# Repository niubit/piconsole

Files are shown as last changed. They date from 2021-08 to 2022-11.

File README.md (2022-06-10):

# PiConsole - Raspberry Pi Pico Retro Console

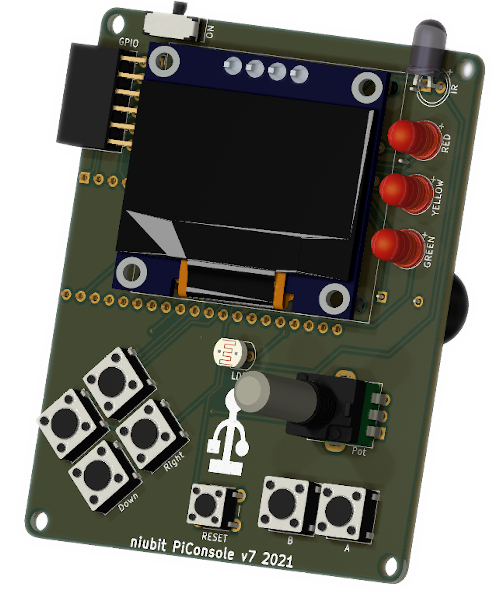
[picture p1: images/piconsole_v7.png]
PiConsole render


This repository has submodules. To clone add the `--recursive` option to the git clone command:

```
git clone --recursive https://github.com/niubit/piconsole.git
```

You can see a brief description (in spanish) in [this site](https://niubitbox.niubit.es/docs/niubitbox005/). A full description in english is available in [Instructables](https://www.instructables.com/PiConsole-Raspberry-Pi-Pico-Retro-Console/).

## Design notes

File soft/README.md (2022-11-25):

# PiConsole Software

Firmware collection for PiConsole.

## Firmware list

### CoderDojo Twin Cities

* Description: Code from the examples that appear on the [MicroPython for Kids](https://www.coderdojotc.org/micropython/) website, a great site that is highly recommended if you want to advance in learning the Python language.
* Folder: [CoderDojo_Twin_Cities](https://github.com/niubit/piconsole_soft/tree/master/CoderDojo_Twin_Cities)
* Environment: MicroPython
    * [oled_displays_pot.py](https://github.com/niubit/piconsole_soft/raw/master/CoderDojo_Twin_Cities/oled_displays_pot.py) + [ssd1306.py](https://github.com/niubit/piconsole_soft/raw/master/CoderDojo_Twin_Cities/ssd1306.py): [OLED Displays > OLED Pot](https://www.coderdojotc.org/micropython/oled/12-oled-pot/)

### MegaGamesCompilationPicoAdafruit

* Description: Collection of 16 games written in C adapted for Raspberry Pi Pico from [this version](https://www.tinyjoypad.com/esp8285) for ESP8266.
* Folder: [MegaGamesCompilationPicoAdafruit](https://github.com/niubit/piconsole_soft/tree/master/MegaGamesCompilationPicoAdafruit)
* Environment: Arduino IDE
* Code: https://github.com/tscha70/MegaGamesCompilationPicoAdafruit
* Installation: [MegaGamesCompilationPicoAdafruit.uf2](https://github.com/niubit/piconsole_soft/raw/master/MegaGamesCompilationPicoAdafruit/MegaGamesCompilationPicoAdafruit.uf2)
* Controls:
    * D-pad: Directions
    * A: Fire

### MorseCodeCreator

* Description: Morse code translator.
* Folder: [MorseCodeCreator](https://github.com/niubit/piconsole_soft/tree/master/MorseCodeCreator)
* Environment: MicroPython
* Original code: https://github.com/printnplay/Pico-MicroPython/blob/main/MorseCodeCreator.py
* Installation: Install [firmware MicroPython](https://micropython.org/download/rp2-pico/) and load the file [MorseCodeCreator.py](https://github.com/niubit/piconsole_soft/raw/master/MorseCodeCreator/MorseCodeCreator.py) (rename as `main.py` for autorun). The output of the program is produced by the USB port, not by the screen. A serial port client must be connected to that port set to 115200 baud.
* Controls:
    * A: Pulse (long or short depending on the time; the red LED lights up when the pulse is short or the green LED lights up when the pulse is long.)

### Phantom Slayer

* Description: Classic game version of Tandy Color Computer Phantom Slayer.
* Folder: [Phantoms](https://github.com/niubit/piconsole_soft/tree/master/Phantoms)
* Environment: [VS Code](https://code.visualstudio.com/)
* Original code: [Site](https://smittytone.net/pico-phantoms/), [Repo](https://github.com/smittytone/pi-pico)
* Installation: [phantoms.uf2](https://github.com/niubit/piconsole_soft/raw/master/Phantoms/phantoms.uf2)
* Controls:
    * Up: Forward
    * Down: Backward
    * Right: Turn right
    * Left: Turn left
    * A: Fire
    * B: Teleport

### PiConsole games

* Description: Simple MicroPython games adapted to the PiConsole hardware.
* Folder: [PiConsole_games](https://github.com/niubit/piconsole_soft/tree/master/PiConsole_games)
* Environment: MicroPython with [web IDE adapted to PiConsole](https://piconsole.niubit.net/).
* Installation: Install [firmware MicroPython](https://micropython.org/download/rp2-pico/) and [lib](https://github.com/niubit/piconsole_soft/tree/master/thumby_mod/lib) directory from `thumby_mod` (this is automatically achieved by using the `FORMAT` button in the [Thumby IDE adapted to PiConsole](https://piconsole.niubit.net/)). Then load the games separately (rename as `main.py` for autorun).

### Tamaguino

* Description: Virtual pet inspired by Tamagotchi.
* Folder: [Tamaguino](https://github.com/niubit/piconsole_soft/tree/master/Tamaguino)
* Environment: Arduino IDE
* Original code: [Site](https://alojzjakob.github.io/Tamaguino/), [Repo](https://github.com/alojzjakob/Tamaguino)
* Installation: [Tamaguino.ino.uf2](https://github.com/niubit/piconsole_soft/raw/master/Tamaguino/Tamaguino.ino.uf2)
* Controls:
    * Up: Menu
    * Down: Status or Accept
    * Right: Back

### Picotamachibi

* Description: Virtual pet inspired by Tamagotchi.
* Folder: [picotamachibi](https://github.com/niubit/piconsole_soft/tree/master/picotamachibi)
* Environment: MicroPython with [web IDE adapted to PiConsole](https://piconsole.niubit.net/).
* Original code: https://github.com/kevinmcaleer/picotamachibi
* Installation: Install [firmware MicroPython](https://micropython.org/download/rp2-pico/). Then load all the files from folder (rename `picotamachibi.py` as `main.py` for autorun).
* Controls:
    * Right: Select
    * A: Accept
    * B: Back

### Colección Cheungbx

* Description: Collection of Python mini-games.
* Folder: [coleccion_cheungbx](https://github.com/niubit/piconsole_soft/tree/master/coleccion_cheungbx)
* Environment: MicroPython
* Original code: https://github.com/niubit/gameESP-micropython/
* Installation: Install [firmware MicroPython](https://micropython.org/download/rp2-pico/) and load the [gameESP.py](https://github.com/niubit/piconsole_soft/raw/master/coleccion_cheungbx/gameESP.py) library. Then the games themselves (rename as `main.py` for autorun).
* Controls:
    * You can toggle between analogue and digital control by pressing Up in the options menu of each game.

### Demo Adafruit para SSD1306 SPI

* Description: Demo of the capabilities of the Adafruit SSD1306 library.
* Folder: [oled_demo](https://github.com/niubit/piconsole_soft/tree/master/oled_demo)
* Environment: Arduino IDE
* Original code: https://github.com/adafruit/Adafruit_SSD1306/blob/master/examples/ssd1306_128x64_spi/ssd1306_128x64_spi.ino
* Installation: Required `Adafruit SSD1306` library. [oled_demo.ino.uf2](https://github.com/niubit/piconsole_soft/raw/master/oled_demo/oled_demo.uf2)

### Pico Invaders

* Description: Vertical screen Space Invaders with analogue control.
* Folder: [picoinvaders](https://github.com/niubit/piconsole_soft/tree/master/picoinvaders)
* Environment: MicroPython
* Original code: https://github.com/printnplay/Pico-MicroPython/blob/main/picoinvaders.py
* Installation: Install [firmware MicroPython](https://micropython.org/download/rp2-pico/) and load the files [picoinvaders.py](https://github.com/niubit/piconsole_soft/raw/master/picoinvaders/picoinvaders.py) (rename as `main.py` for autorun) and [ssd1306.py](https://github.com/niubit/piconsole_soft/raw/master/picoinvaders/ssd1306.py).
* Controls:
    * Potentiometer: Movement
    * Auto fire

### Pico Invaders with buttons

* Description: Vertical screen Space Invaders with digital control.
* Folder: [picoinvaders_with_buttons](https://github.com/niubit/piconsole_soft/tree/master/picoinvaders_with_buttons)
* Environment: MicroPython
* Original code: https://github.com/printnplay/Pico-MicroPython/blob/main/PicoInvadersWithButtons.py
* Installation: Install [firmware MicroPython](https://micropython.org/download/rp2-pico/) and load the files [PicoInvadersWithButtons.py](https://github.com/niubit/piconsole_soft/raw/master/picoinvaders_with_buttons/PicoInvadersWithButtons.py) (rename as `main.py` for autorun) and [ssd1306.py](https://github.com/niubit/piconsole_soft/raw/master/picoinvaders_with_buttons/ssd1306.py).
* Controls:
    * Up/Down: Movement (left/right)
    * A: Fire

### Reflejos2

* Description: A reaction game for two players. The code is only 32 lines long so it is easy to follow and is an example of how much can be done with few lines of code. On start-up, the red LED lights up for 5 to 10 seconds. Players must press their button as soon as they see the light go out. When they do so, the screen shows which of the two players was the fastest.
* Folder: [reflejos2](https://github.com/niubit/piconsole_soft/tree/master/reflejos2)
* Environment: MicroPython
* Installation: Install [firmware MicroPython](https://micropython.org/download/rp2-pico/) and load the files [reflejos2.py](https://github.com/niubit/piconsole_soft/raw/master/reflejos2/reflejos2.py) (rename as `main.py` for autorun) and [ssd1306.py](https://github.com/niubit/piconsole_soft/raw/master/reflejos2/ssd1306.py).
* Controls:
    * A: Player 1
    * B: Player 2

### Test PiConsole

* Description: PiConsole I/O test program.
* Folder: [test_piconsole](https://github.com/niubit/piconsole_soft/tree/master/test_piconsole)
* Environment: Arduino IDE
* Installation: Librería `Adafruit SSD1306` needed. [test_piconsole.uf2](https://github.com/niubit/piconsole_soft/raw/master/test_piconsole/test_piconsole.uf2)
* Controls:
    * Up: Lights up IR LED (view it through a mobile phone camera)
    * Left: Lights up red LED
    * Right: Lights up yellow LED
    * Down: Lights up green LED
    * A y B: Beeps
    * Potentiometer: Controls top bar on screen
    * Photoresistor LDR: Controls bottom bar on screen

### Games Thumby

* Description: Games made for Thumby by the community, compatible with PiConsole.
* Folder: [thumby_games](https://github.com/niubit/piconsole_soft/tree/master/thumby_games)
* Environment: MicroPython with [web IDE adapted to PiConsole](https://piconsole.niubit.net/).
* Installation: Install [firmware MicroPython](https://micropython.org/download/rp2-pico/) and [lib](https://github.com/niubit/piconsole_soft/tree/master/thumby_mod/lib) directory from `thumby_mod` (this is automatically achieved by using the `FORMAT` button in the [Thumby IDE adapted to PiConsole](https://piconsole.niubit.net/)). Then load the games separately (rename to `main.py` to make it run automatically).

### Adaptation of the Thumby platform

* Description: [Thumby](https://www.indiegogo.com/projects/thumby-the-tiny-playable-keychain#/) default games. These are the same games that are installed by using the `FORMAT` button in the [Thumby IDE adapted to PiConsole](https://piconsole.niubit.net/).
* Folder: [thumby_mod](https://github.com/niubit/piconsole_soft/tree/master/thumby_mod)
* Environment: MicroPython with [web IDE adapted to PiConsole](https://piconsole.niubit.net/).
* Original code: https://github.com/TinyCircuits/tinycircuits.github.io/tree/master/ThumbyGames
* Installation: Install [firmware MicroPython](https://micropython.org/download/rp2-pico/) and upload all the files following the directory structure.
* Controls: D-pad + A + B

### CHIP-8 emulator

* Description: [CHIP-8](https://es.wikipedia.org/wiki/CHIP-8) virtual system emulator.
* Folder: [chip-8_emulator](https://github.com/niubit/piconsole_soft/tree/master/chip-8_emulator)
* Environment: MicroPython with [web IDE adapted to PiConsole](https://piconsole.niubit.net/).
* Original code: https://github.com/Wireframe-Magazine/Wireframe-54/tree/main/emulator-guide/pychip8
* Installation: Install [firmware MicroPython](https://micropython.org/download/rp2-pico/) and upload all the files following the directory structure.
* Controls: D-pad + A + B mapped in file `cpu.py`

## Pins - Components

* Pot
    * ADC1
* LDR
    * ADC2
* LED
    * GP8 -> Yellow
    * GP9 -> Red
    * GP21 -> Green
    * GP22 -> IR
* Buzzer
    * GP10
* Controls
    * GP11 -> Fire A
    * GP7  -> Fire B
    * GP12 -> Right
    * GP13 -> Left
    * GP14 -> Down
    * GP15 -> Up
* OLED
    * GP16 -> DC
    * GP17 -> CS
    * GP18 -> SCL  //SCK
    * GP19 -> SDA  //MOSI
    * GP20 -> RES

## Arduino IDE environment

Follow [this instructions](https://arduino-pico.readthedocs.io/en/latest/install.html#installing-via-arduino-boards-manager) to add the Pico as a supported board in Arduino IDE.

## Libraries

* MicroPython
    * https://github.com/adafruit/micropython-adafruit-ssd1306
    * https://github.com/adafruit/micropython-adafruit-gfx
* CircuitPython
    * https://github.com/adafruit/Adafruit_CircuitPython_SSD1306
    * https://github.com/adafruit/Adafruit_CircuitPython_GFX

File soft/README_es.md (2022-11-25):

# PiConsole Software

Colección de firmware para PiConsole.

## Lista de firmware

### CoderDojo Twin Cities

* Descripción: Código de los ejemplos que aparecen en la web [MicroPython for Kids](https://www.coderdojotc.org/micropython/), un gran sitio muy recomendable si se quiere avanzar en el aprendizaje del lenguaje Python.
* Directorio: [CoderDojo_Twin_Cities](https://github.com/niubit/piconsole_soft/tree/master/CoderDojo_Twin_Cities)
* Entorno: MicroPython
    * [oled_displays_pot.py](https://github.com/niubit/piconsole_soft/raw/master/CoderDojo_Twin_Cities/oled_displays_pot.py) + [ssd1306.py](https://github.com/niubit/piconsole_soft/raw/master/CoderDojo_Twin_Cities/ssd1306.py): [OLED Displays > OLED Pot](https://www.coderdojotc.org/micropython/oled/12-oled-pot/)

### MegaGamesCompilationPicoAdafruit

* Descripción: Colección de 16 juegos escritos en C adaptados para Raspberry Pi Pico de [esta versión](https://www.tinyjoypad.com/esp8285) para ESP8266.
* Directorio: [MegaGamesCompilationPicoAdafruit](https://github.com/niubit/piconsole_soft/tree/master/MegaGamesCompilationPicoAdafruit)
* Entorno: Arduino IDE
* Código: https://github.com/tscha70/MegaGamesCompilationPicoAdafruit
* Instalación: [MegaGamesCompilationPicoAdafruit.uf2](https://github.com/niubit/piconsole_soft/raw/master/MegaGamesCompilationPicoAdafruit/MegaGamesCompilationPicoAdafruit.uf2)
* Controles:
    * Cruceta: Direcciones
    * A: Disparo

### MorseCodeCreator

* Descripción: Traductor de código Morse.
* Directorio: [MorseCodeCreator](https://github.com/niubit/piconsole_soft/tree/master/MorseCodeCreator)
* Entorno: MicroPython
* Código original: https://github.com/printnplay/Pico-MicroPython/blob/main/MorseCodeCreator.py
* Instalación: Instalar [firmware MicroPython](https://micropython.org/download/rp2-pico/) y cargar el archivo [MorseCodeCreator.py](https://github.com/niubit/piconsole_soft/raw/master/MorseCodeCreator/MorseCodeCreator.py) (renombrar a `main.py` para que se ejecute automáticamente). La salida del programa se produce por el puerto USB, no por pantalla. Hay que conectar un cliente de puerto serie a ese puerto configurado a 115200 baudios.
* Controles:
    * A: Pulso (largo o corto según el tiempo; se enciende el LED rojo en pulso corto o el verde al hacerse largo)

### Phantom Slayer

* Descripción: Versión de juego clásico de Tandy Color Computer Phantom Slayer.
* Directorio: [Phantoms](https://github.com/niubit/piconsole_soft/tree/master/Phantoms)
* Entorno: [VS Code](https://code.visualstudio.com/)
* Código original: [Sitio](https://smittytone.net/pico-phantoms/), [Repo](https://github.com/smittytone/pi-pico)
* Instalación: [phantoms.uf2](https://github.com/niubit/piconsole_soft/raw/master/Phantoms/phantoms.uf2)
* Controles:
    * Arriba: Adelante
    * Abajo: Atrás
    * Derecha: Girar derecha
    * Izquierda: Girar izquierda
    * A: Disparo
    * B: Teletransporte

### Juegos PiConsole

* Descripción: Juegos sencillos MicroPython adaptados al hardware de PiConsole.
* Directorio: [PiConsole_games](https://github.com/niubit/piconsole_soft/tree/master/PiConsole_games)
* Entorno: MicroPython con [IDE web adaptado a PiConsole](https://piconsole.niubit.net/).
* Instalación: Instalar [firmware MicroPython](https://micropython.org/download/rp2-pico/) y directorio [lib](https://github.com/niubit/piconsole_soft/tree/master/thumby_mod/lib) de `thumby_mod` (esto mismo se logra automáticamente usando el botón `FORMAT` en el [IDE de Thumby adaptado a PiConsole](https://piconsole.niubit.net/)). Luego cargar los juegos por separado (renombrar a `main.py` para que se ejecute automáticamente).

### Tamaguino

* Descripción: Mascota virtual inspirada en Tamagotchi.
* Directorio: [Tamaguino](https://github.com/niubit/piconsole_soft/tree/master/Tamaguino)
* Entorno: Arduino IDE
* Código original: [Sitio](https://alojzjakob.github.io/Tamaguino/), [Repo](https://github.com/alojzjakob/Tamaguino)
* Instalación: [Tamaguino.ino.uf2](https://github.com/niubit/piconsole_soft/raw/master/Tamaguino/Tamaguino.ino.uf2)
* Controles:
    * Arriba: Menú
    * Abajo: Estado o Aceptar
    * Derecha: Salir

### Picotamachibi

* Descripción: Mascota virtual inspirada en Tamagotchi.
* Directorio: [picotamachibi](https://github.com/niubit/piconsole_soft/tree/master/picotamachibi)
* Entorno: MicroPython con [IDE web adaptado a PiConsole](https://piconsole.niubit.net/).
* Código original: https://github.com/kevinmcaleer/picotamachibi
* Instalación: Instalar [firmware MicroPython](https://micropython.org/download/rp2-pico/). Luego todos los ficheros del directorio (renombrando `picotamachibi.py` a `main.py` para que se ejecute automáticamente).
* Controles:
    * Derecha: Seleccionar
    * A: Aceptar
    * B: Cancelar

### Colección Cheungbx

* Descripción: Colección de minijuegos Python.
* Directorio: [coleccion_cheungbx](https://github.com/niubit/piconsole_soft/tree/master/coleccion_cheungbx)
* Entorno: MicroPython
* Código original: https://github.com/niubit/gameESP-micropython/
* Instalación: Instalar [firmware MicroPython](https://micropython.org/download/rp2-pico/) y cargar la librería [gameESP.py](https://github.com/niubit/piconsole_soft/raw/master/coleccion_cheungbx/gameESP.py). Luego los juegos propiamente dichos (renombrando a `main.py` para que se ejecuten automáticamente).
* Controles:
    * Se puede alternar entre control analógico o digital al pulsar Arriba en el menú de opciones de cada juego.

### Demo Adafruit para SSD1306 SPI

* Descripción: Demo de las capacidades de la librería SSD1306 de Adafruit.
* Directorio: [oled_demo](https://github.com/niubit/piconsole_soft/tree/master/oled_demo)
* Entorno: Arduino IDE
* Código original: https://github.com/adafruit/Adafruit_SSD1306/blob/master/examples/ssd1306_128x64_spi/ssd1306_128x64_spi.ino
* Instalación: Necesaria librería `Adafruit SSD1306`. [oled_demo.ino.uf2](https://github.com/niubit/piconsole_soft/raw/master/oled_demo/oled_demo.uf2)

### Pico Invaders

* Descripción: Space Invaders de pantalla vertical con control analógico.
* Directorio: [picoinvaders](https://github.com/niubit/piconsole_soft/tree/master/picoinvaders)
* Entorno: MicroPython
* Código original: https://github.com/printnplay/Pico-MicroPython/blob/main/picoinvaders.py
* Instalación: Instalar [firmware MicroPython](https://micropython.org/download/rp2-pico/) y cargar los archivos [picoinvaders.py](https://github.com/niubit/piconsole_soft/raw/master/picoinvaders/picoinvaders.py) (renombrar a `main.py` para que se ejecute automáticamente) y [ssd1306.py](https://github.com/niubit/piconsole_soft/raw/master/picoinvaders/ssd1306.py).
* Controles:
    * Potenciómetro: Movimiento
    * Disparo automático

### Pico Invaders con botones

* Descripción: Space Invaders de pantalla vertical con control digital.
* Directorio: [picoinvaders_with_buttons](https://github.com/niubit/piconsole_soft/tree/master/picoinvaders_with_buttons)
* Entorno: MicroPython
* Código original: https://github.com/printnplay/Pico-MicroPython/blob/main/PicoInvadersWithButtons.py
* Instalación: Instalar [firmware MicroPython](https://micropython.org/download/rp2-pico/) y cargar los archivos [PicoInvadersWithButtons.py](https://github.com/niubit/piconsole_soft/raw/master/picoinvaders_with_buttons/PicoInvadersWithButtons.py) (renombrar a `main.py` para que se ejecute automáticamente) y [ssd1306.py](https://github.com/niubit/piconsole_soft/raw/master/picoinvaders_with_buttons/ssd1306.py).
* Controles:
    * Arriba/Abajo: Movimiento (izquierda/derecha)
    * A: Disparo

### Reflejos2

* Descripción: Juego de reflejos para dos jugadores. El código sólo tiene 32 líneas por lo que resulta fácil de seguir y es un ejemplo de lo mucho que se puede hacer con poco código. Al arrancar, se enciende el LED rojo entre 5 y 10 segundos. Los jugadores deben pulsar su botón nada más ver apagarse la luz. Al hacerlo se muestra en pantalla cual de los dos ha sido el más rápido.
* Directorio: [reflejos2](https://github.com/niubit/piconsole_soft/tree/master/reflejos2)
* Entorno: MicroPython
* Instalación: Instalar [firmware MicroPython](https://micropython.org/download/rp2-pico/) y cargar el archivo [reflejos2.py](https://github.com/niubit/piconsole_soft/raw/master/reflejos2/reflejos2.py) (renombrar a `main.py` para que se ejecute automáticamente) y [ssd1306.py](https://github.com/niubit/piconsole_soft/raw/master/reflejos2/ssd1306.py).
* Controles:
    * A: Jugador 1
    * B: Jugador 2

### Test PiConsole

* Descripción: Programa de test de entradas y salidas de PiConsole.
* Directorio: [test_piconsole](https://github.com/niubit/piconsole_soft/tree/master/test_piconsole)
* Entorno: Arduino IDE
* Instalación: Necesaria librería `Adafruit SSD1306`. [test_piconsole.uf2](https://github.com/niubit/piconsole_soft/raw/master/test_piconsole/test_piconsole.uf2)
* Controles:
    * Arriba => Enciende LED IR (visualizarlo a través de la cámara de un teléfono móvil)
    * Izquierda => Enciende LED rojo
    * Derecha => Enciende LED amarillo
    * Abajo => Enciende LED verde
    * Controles A y B => Hace sonar el zumbador
    * Potenciómetro => Controla barra superior en pantalla
    * Fotorresistencia LDR => Controla barra inferior en pantalla

### Juegos Thumby

* Descripción: Juegos hechos para Thumby por la comunidad, compatibles con PiConsole.
* Directorio: [thumby_games](https://github.com/niubit/piconsole_soft/tree/master/thumby_games)
* Entorno: MicroPython con [IDE web adaptado a PiConsole](https://piconsole.niubit.net/).
* Instalación: Instalar [firmware MicroPython](https://micropython.org/download/rp2-pico/) y directorio [lib](https://github.com/niubit/piconsole_soft/tree/master/thumby_mod/lib) de `thumby_mod` (esto mismo se logra automáticamente usando el botón `FORMAT` en el [IDE de Thumby adaptado a PiConsole](https://piconsole.niubit.net/)). Luego cargar los juegos por separado (renombrar a `main.py` para que se ejecute automáticamente).

### Adaptación plataforma Thumby

* Descripción: Juegos predeterminados de [Thumby](https://www.indiegogo.com/projects/thumby-the-tiny-playable-keychain#/). Son los mismos juegos que se instalan al usar el botón `FORMAT` en el [IDE de Thumby adaptado a PiConsole](https://piconsole.niubit.net/).
* Directorio: [thumby_mod](https://github.com/niubit/piconsole_soft/tree/master/thumby_mod)
* Entorno: MicroPython con [IDE web adaptado a PiConsole](https://piconsole.niubit.net/).
* Código original: https://github.com/TinyCircuits/tinycircuits.github.io/tree/master/ThumbyGames
* Instalación: Instalar [firmware MicroPython](https://micropython.org/download/rp2-pico/) y cargar todos los archivos siguiendo la estructura de directorios.
* Controles: Cruceta + A + B

### Emulador CHIP-8

* Descripción: Emulador del sistema virtual [CHIP-8](https://es.wikipedia.org/wiki/CHIP-8).
* Directorio: [chip-8_emulator](https://github.com/niubit/piconsole_soft/tree/master/chip-8_emulator)
* Entorno: MicroPython con [IDE web adaptado a PiConsole](https://piconsole.niubit.net/).
* Código original: https://github.com/Wireframe-Magazine/Wireframe-54/tree/main/emulator-guide/pychip8
* Instalación: Instalar [firmware MicroPython](https://micropython.org/download/rp2-pico/) y cargar todos los archivos siguiendo la estructura de directorios.
* Controles: Cruceta + A + B mapeables en fichero `cpu.py`

## Pines - Componentes

* Pot
    * ADC1
* LDR
    * ADC2
* LED
    * GP8 -> Amarillo
    * GP9 -> Rojo
    * GP21 -> Verde
    * GP22 -> IR
* Buzzer
    * GP10
* Controles
    * GP11 -> Disparo A
    * GP7  -> Disparo B
    * GP12 -> Derecha
    * GP13 -> Izquierda
    * GP14 -> Abajo
    * GP15 -> Arriba
* OLED
    * GP16 -> DC
    * GP17 -> CS
    * GP18 -> SCL  //SCK
    * GP19 -> SDA  //MOSI
    * GP20 -> RES

## Entorno Arduino IDE

Seguir [estas instrucciones](https://arduino-pico.readthedocs.io/en/latest/install.html#installing-via-arduino-boards-manager) para añadir la Pico como placa soportada en Arduino IDE.

## Librerías

* MicroPython
    * https://github.com/adafruit/micropython-adafruit-ssd1306
    * https://github.com/adafruit/micropython-adafruit-gfx
* CircuitPython
    * https://github.com/adafruit/Adafruit_CircuitPython_SSD1306
    * https://github.com/adafruit/Adafruit_CircuitPython_GFX

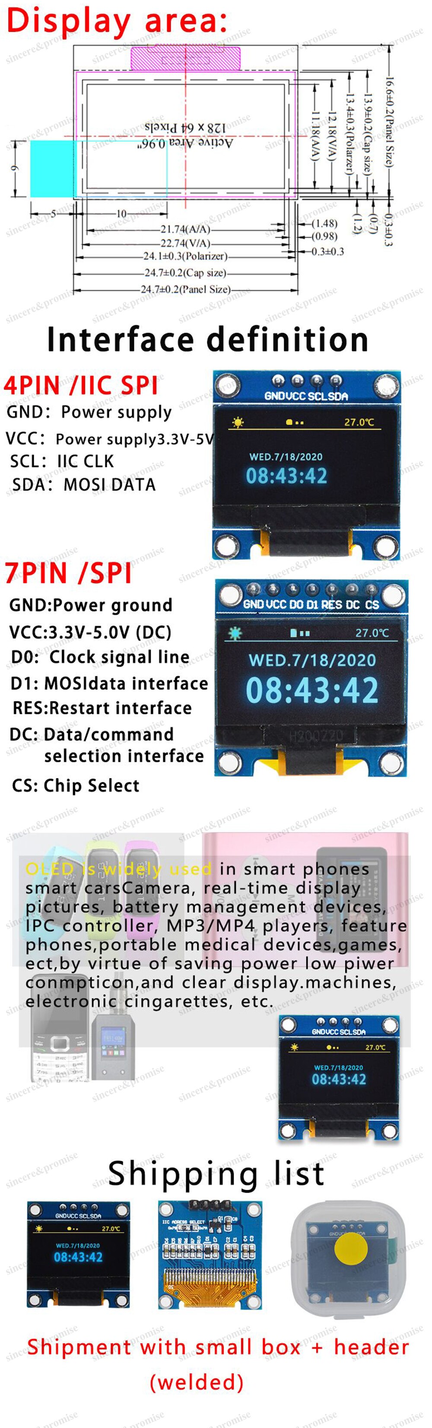
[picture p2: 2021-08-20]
pcb/images/oled2.jpg

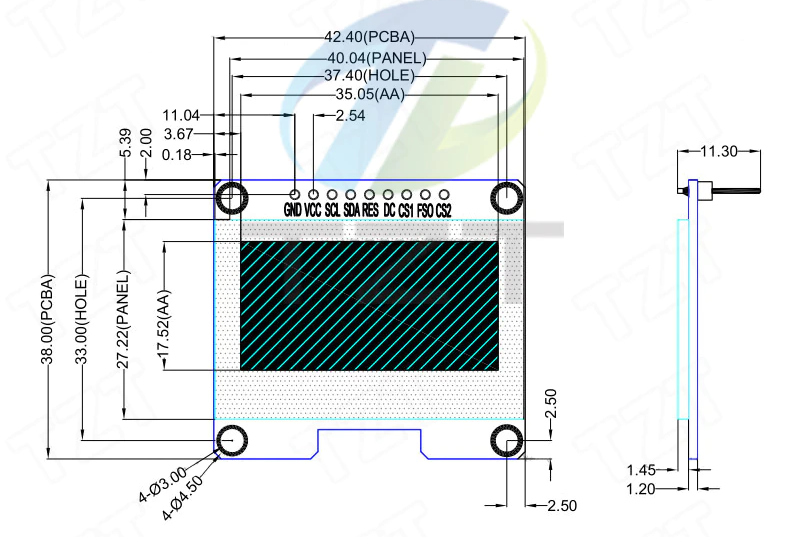
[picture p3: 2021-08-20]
pcb/images/ssd1309_dim.png

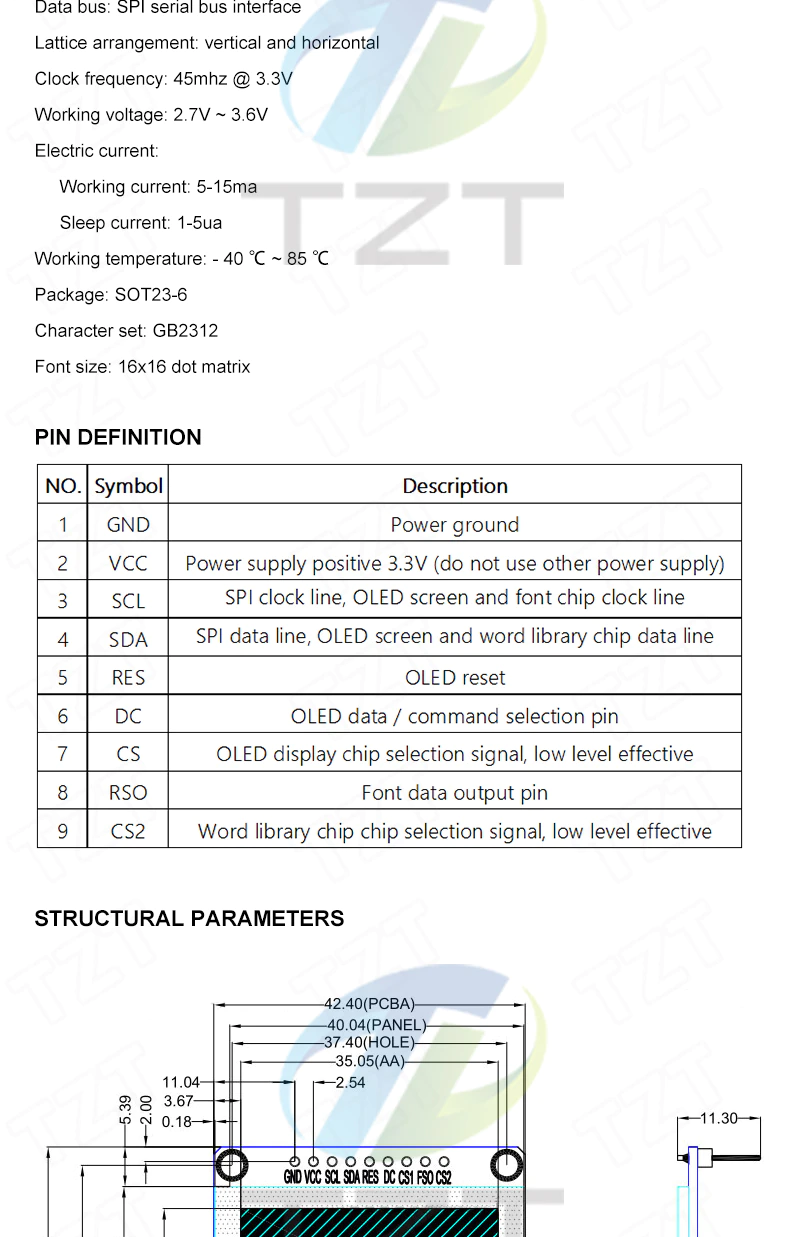
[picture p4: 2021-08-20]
pcb/images/ssd1309_1.png

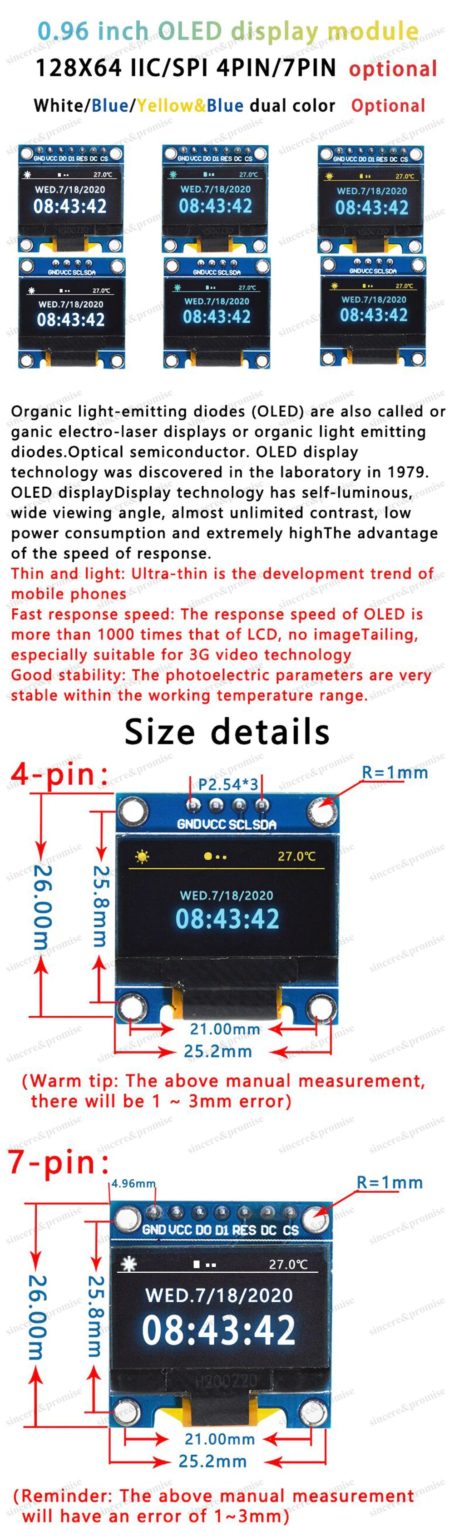
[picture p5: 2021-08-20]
pcb/images/oled1.jpg

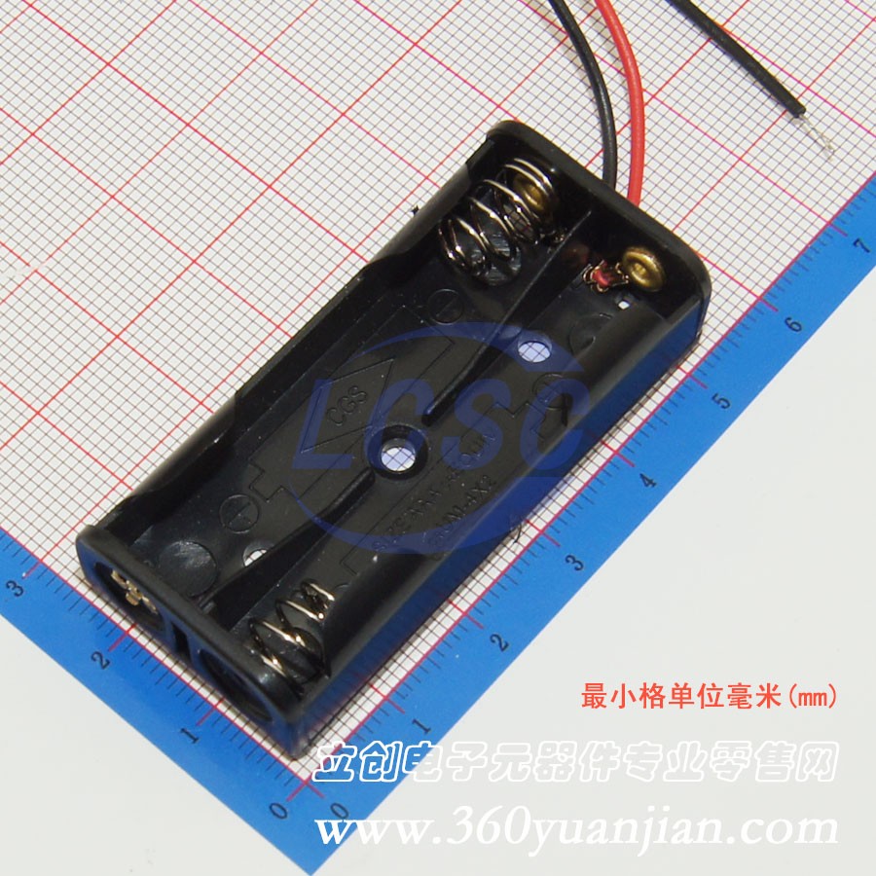
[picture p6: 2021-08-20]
pcb/images/battery_holder.jpg

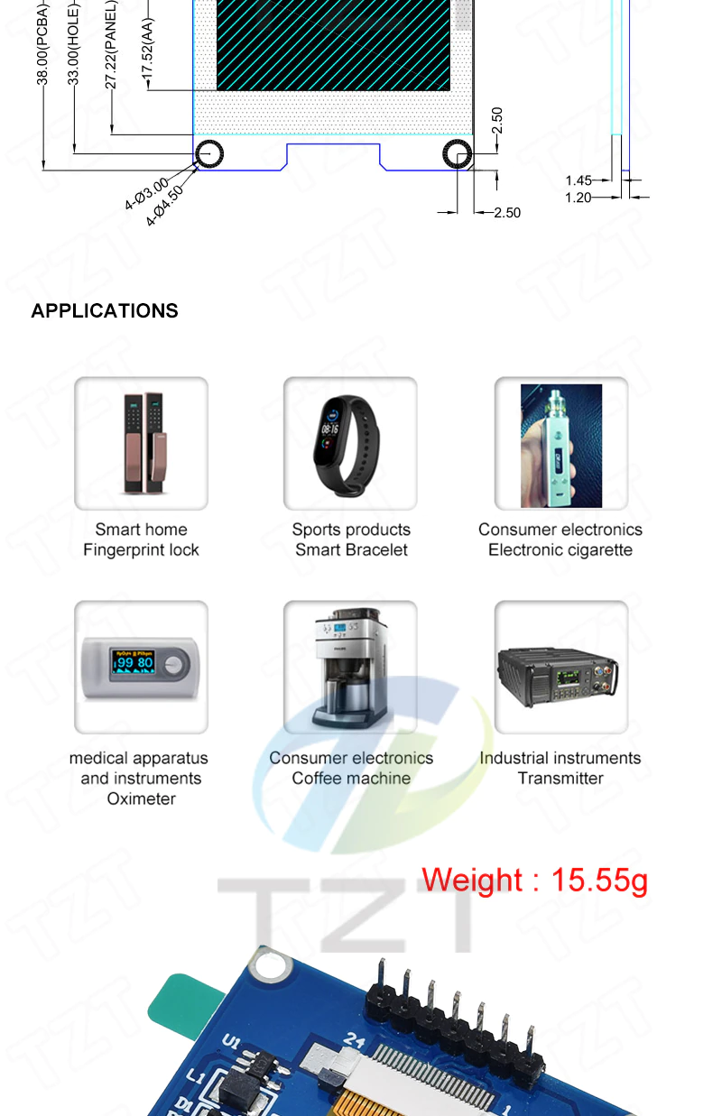
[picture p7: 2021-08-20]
pcb/images/ssd1309_2.png

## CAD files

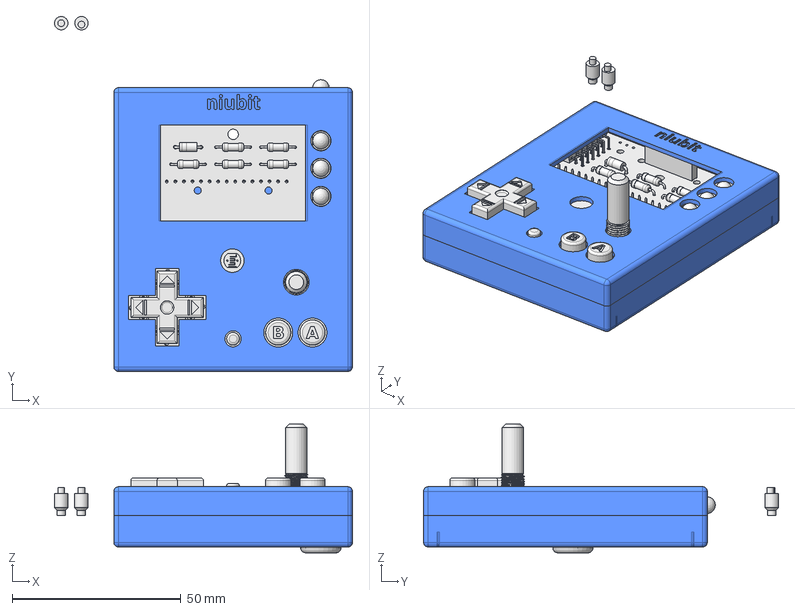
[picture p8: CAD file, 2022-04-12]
case/case.FCStd
88.4 x 105.3 x 38.2 mm
spacer_desviado
spacer_recto
pcb
cruceta
tecla_b001
tecla_a001
tecla_reset
inferior001
superior009

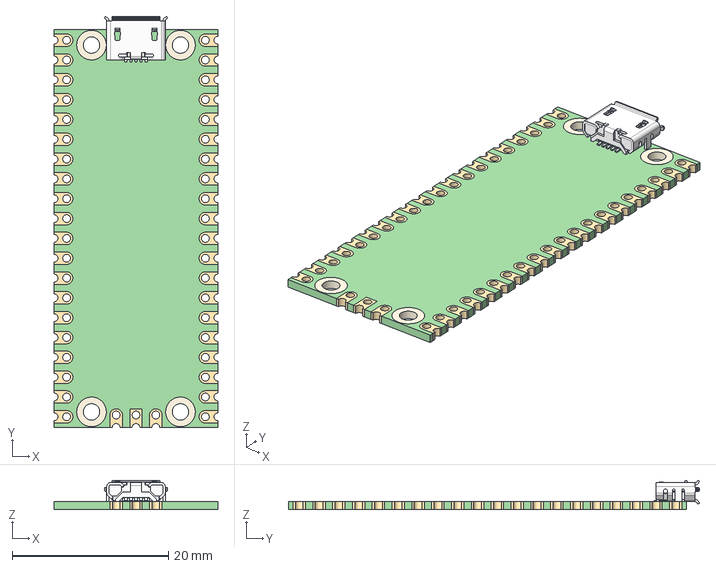
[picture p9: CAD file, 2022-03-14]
pcb/3d_models/Raspberry_Pi_Pico.step
21.0 x 52.7 x 3.73 mm
PCB
Micro-USB_breakout v2

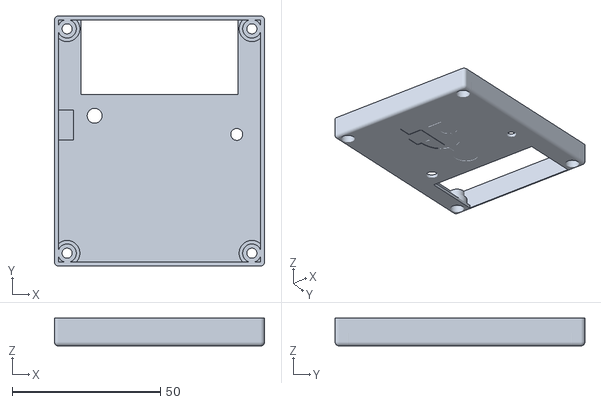
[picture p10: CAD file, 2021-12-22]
case/inferior.stl
70.8 x 84.2 x 9.40

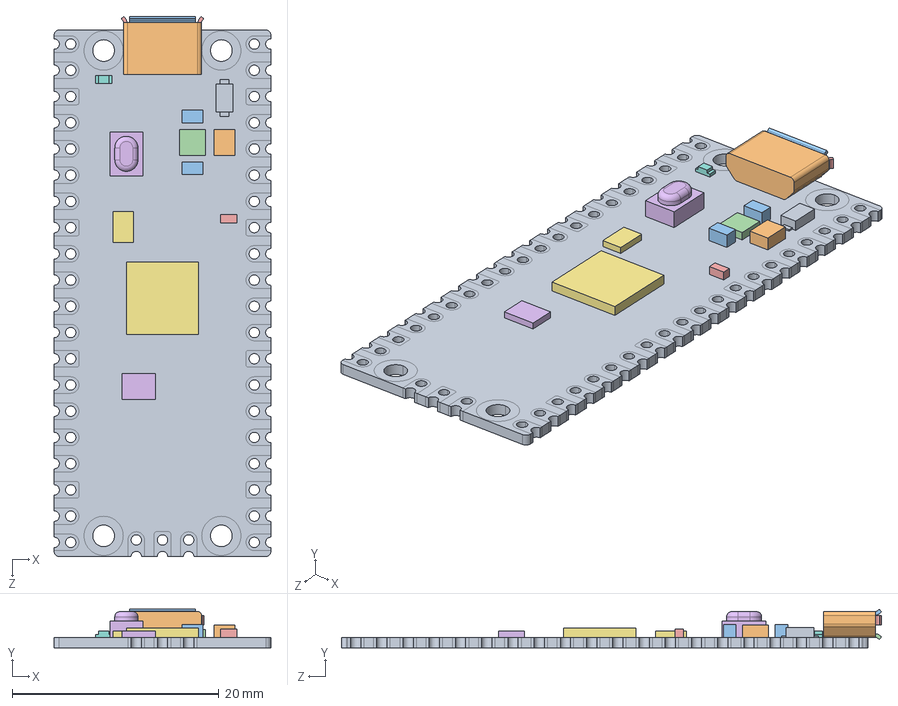
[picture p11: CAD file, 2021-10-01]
pcb/3d_models/Pico-R3.step
21.0 x 3.73 x 52.3 mm
PICO_REF_BOARD.STEP
PICO_REF_USB.STEP
PICO_REF_SWITCH.STEP
PICO_REF_MICROCONTROLLER.STEP
PICO_REF_LED.STEP
PICO_REF_ONSEMI.STEP
PICO_BOURNS.STEP
PICO_MURATA.STEP x 2
PICO_RICHTEK.STEP
PICO_DIODES.STEP
PICO_AEL.STEP
PICO_WINBOND.STEP

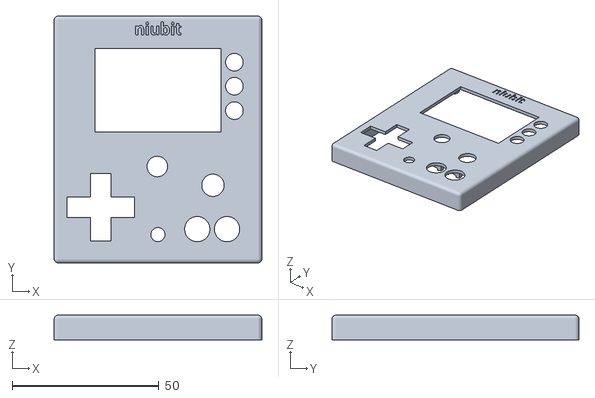
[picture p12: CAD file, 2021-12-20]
case/superior.stl
70.8 x 84.2 x 8.50

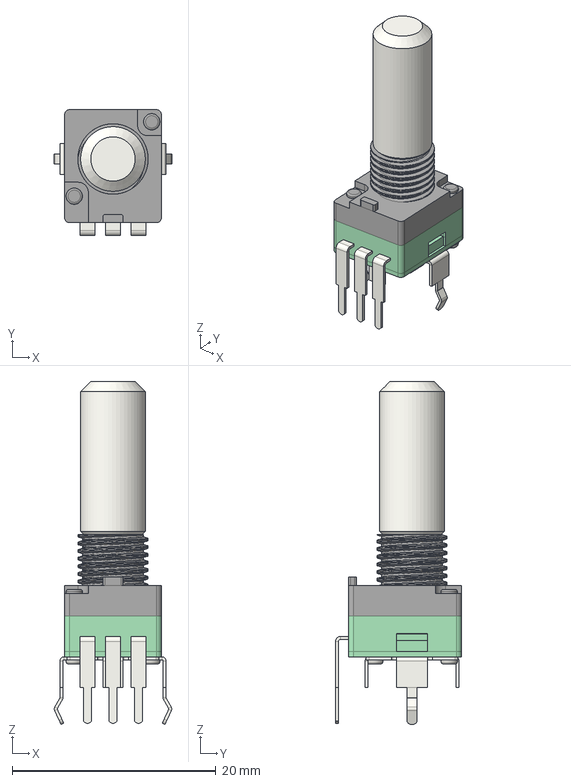
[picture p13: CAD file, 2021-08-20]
pcb/3d_models/ALPHA-RD901F-40.step
11.5 x 12.4 x 33.6 mm

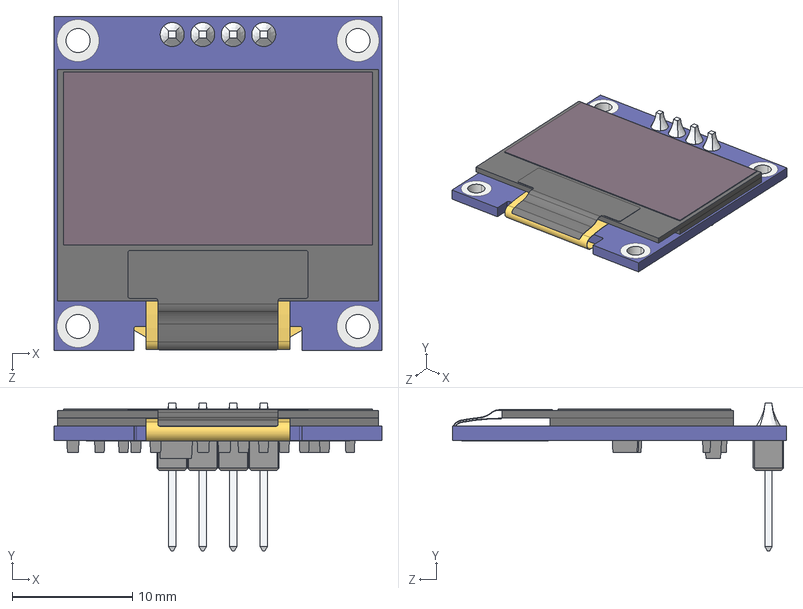
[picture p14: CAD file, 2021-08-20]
pcb/3d_models/OLED TFT 0.96 inch 64x128 monochrome.STEP
27.3 x 12.3 x 27.8 mm

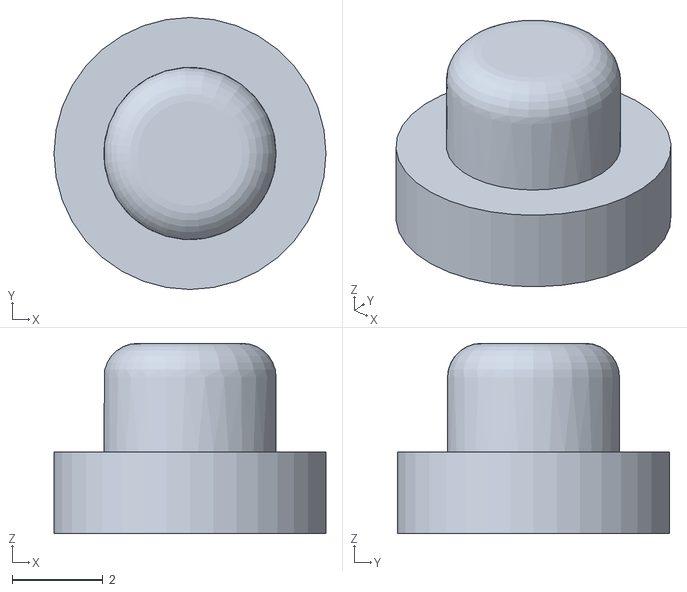
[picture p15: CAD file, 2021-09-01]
case/tecla_reset.stl
6.00 x 6.00 x 4.20

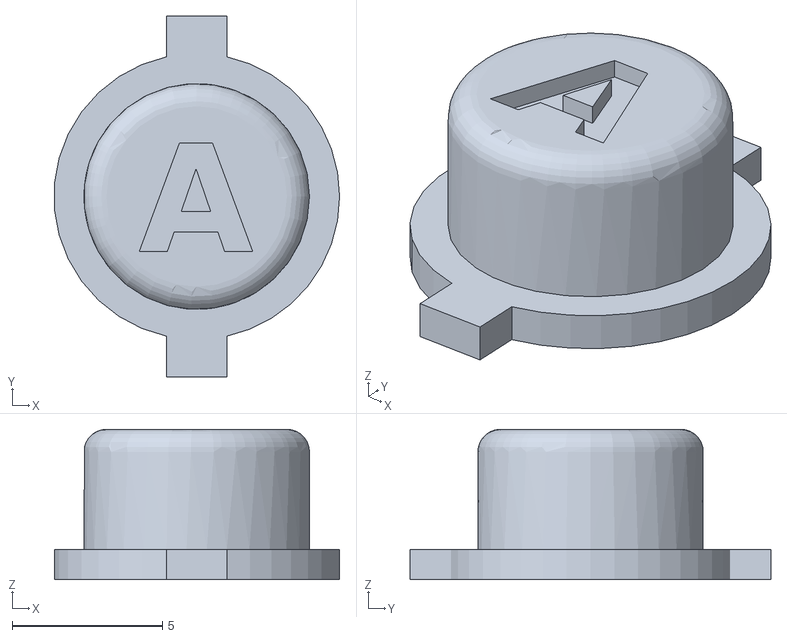
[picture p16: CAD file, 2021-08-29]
case/tecla_a.stl
9.48 x 12.0 x 5.00

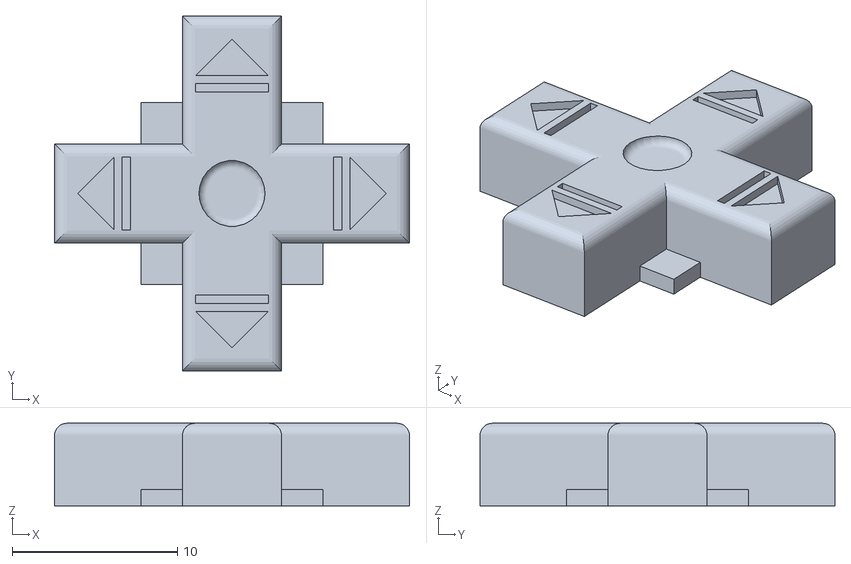
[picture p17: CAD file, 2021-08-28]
case/cruceta.stl
21.5 x 21.5 x 5.00

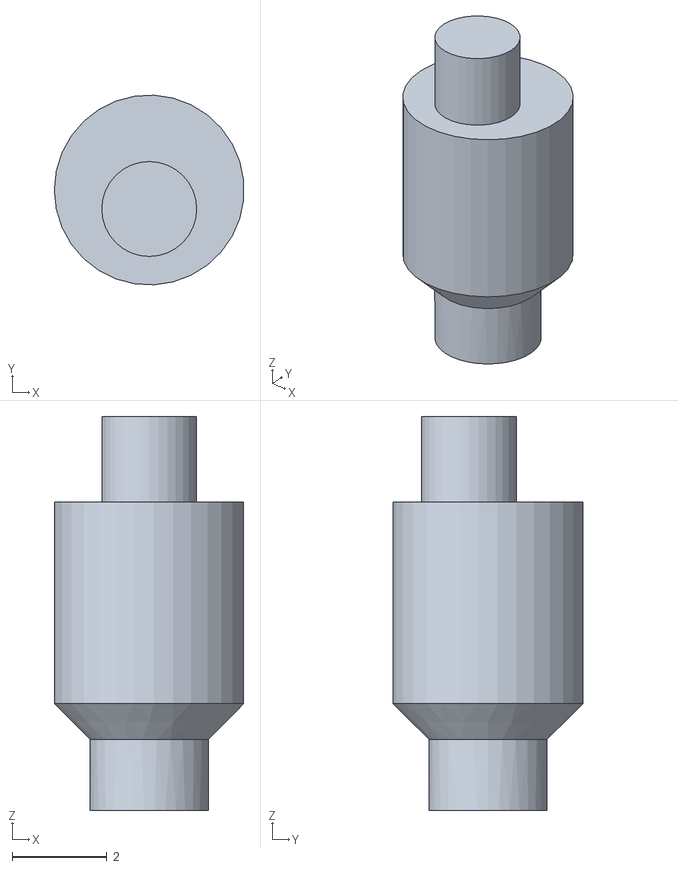
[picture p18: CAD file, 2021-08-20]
case/spacer_desviado.stl
3.99 x 3.99 x 8.30

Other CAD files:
case/superior_liso.stl
case/inferior_liso.stl
case/tecla_b.stl
case/spacer_recto.stl

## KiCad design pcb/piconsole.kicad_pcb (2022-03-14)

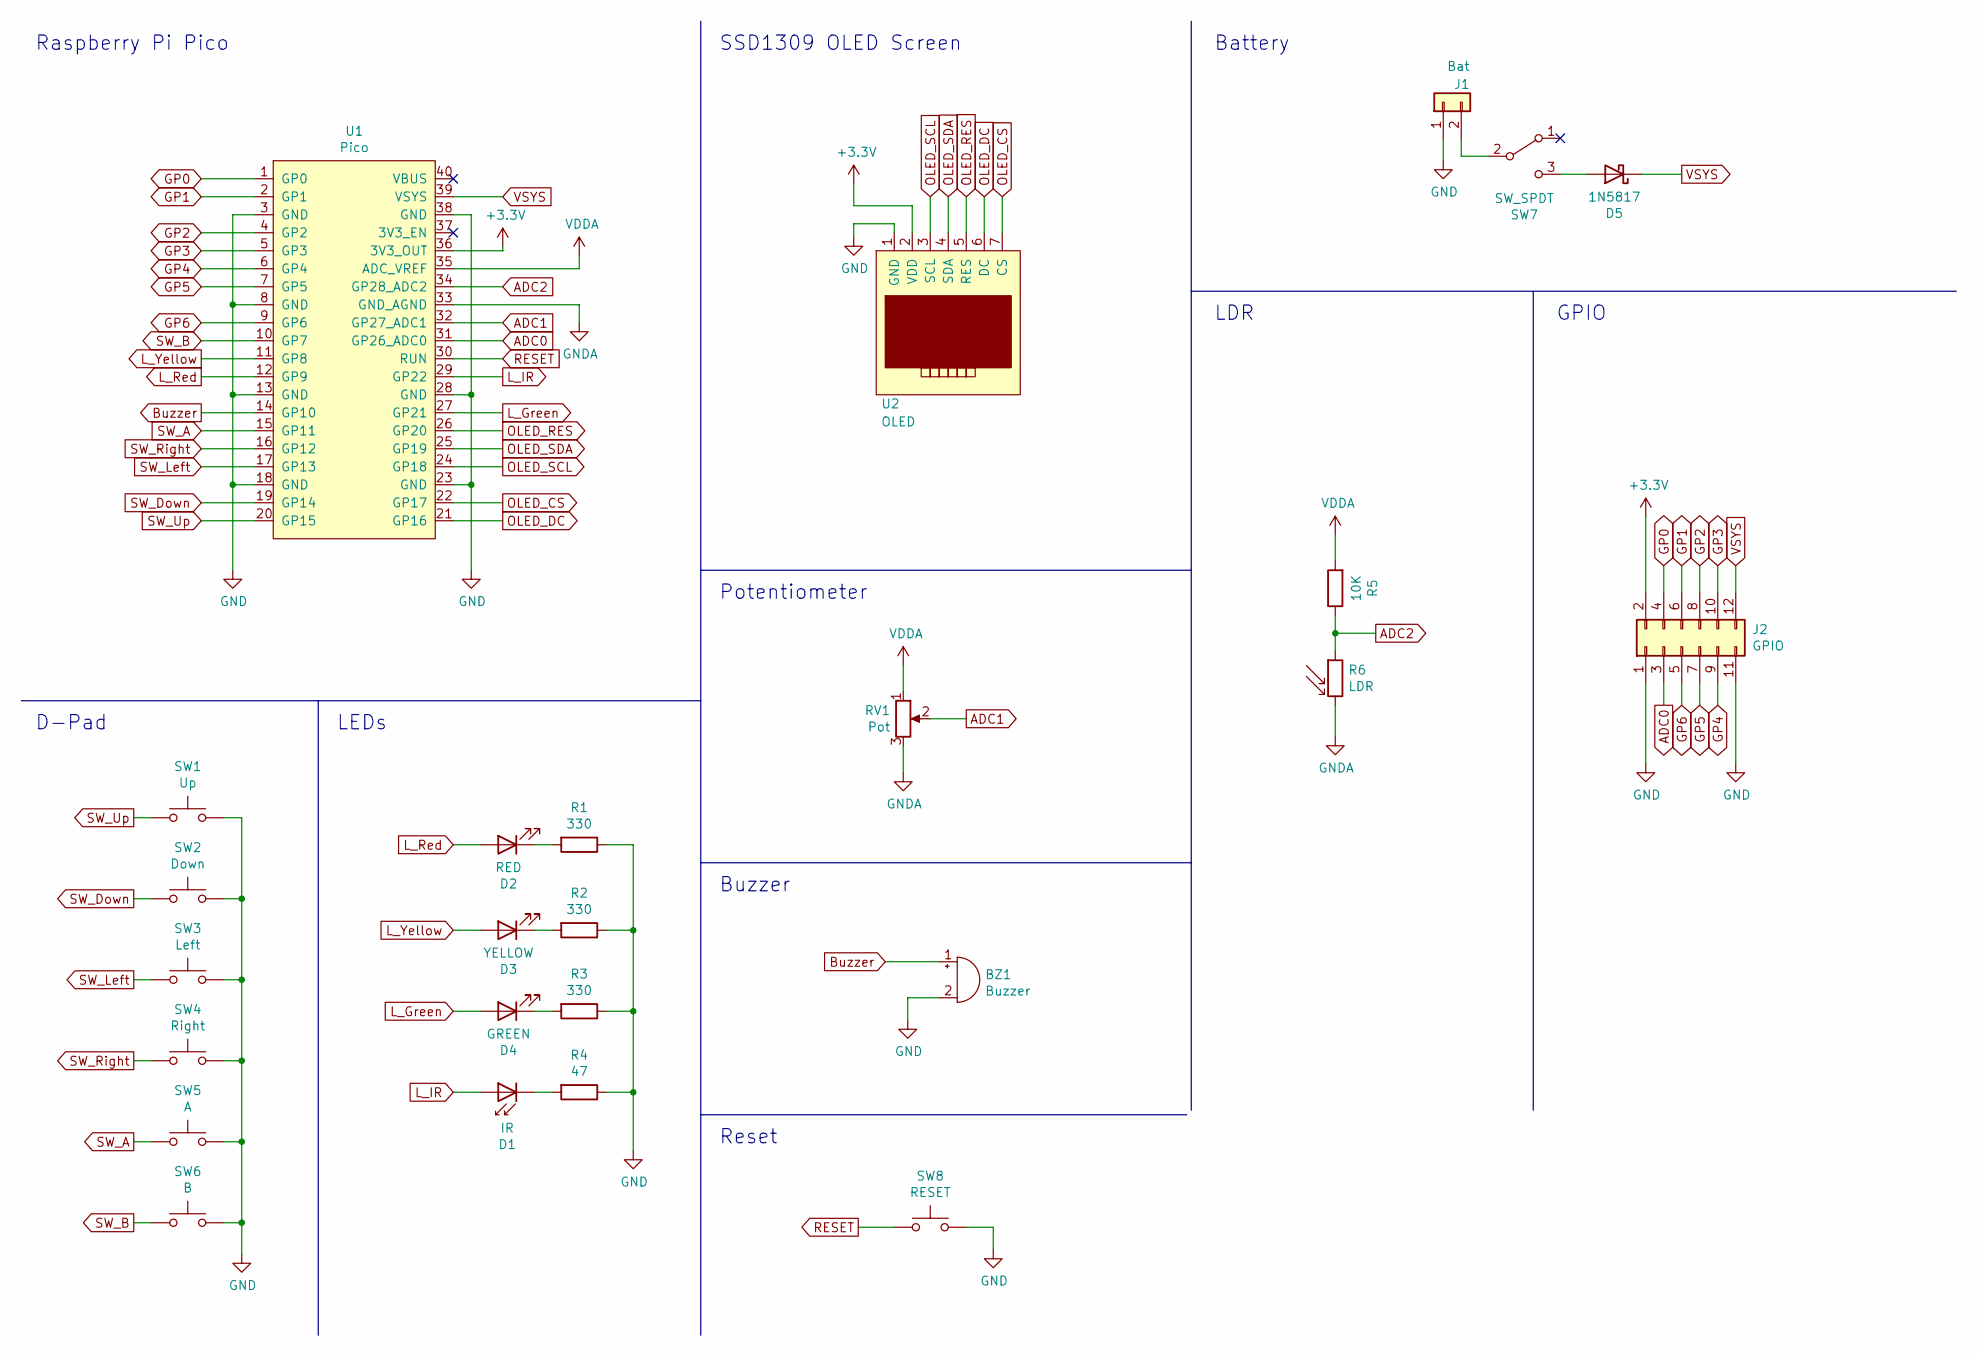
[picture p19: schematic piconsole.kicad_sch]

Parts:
BZ1: Buzzer; MagneticBuzzer_ProSignal_ABT-410-RC
D1: IR; LED_D5.0mm_IRGrey
D2: RED; LED_D5.0mm
D3: YELLOW; LED_D5.0mm
D4: GREEN; LED_D5.0mm
D5: 1N5817; D_DO-41_SOD81_P7.62mm_Horizontal
J1: Bat; PinHeader_1x02_P2.54mm_Vertical
J2: GPIO; PinSocket_2x06_P2.54mm_Horizontal
R1, R2, R3: 330; R_Axial_DIN0207_L6.3mm_D2.5mm_P10.16mm_Horizontal
R4: 47; R_Axial_DIN0207_L6.3mm_D2.5mm_P10.16mm_Horizontal
R5: 10K; R_Axial_DIN0207_L6.3mm_D2.5mm_P10.16mm_Horizontal
R6: LDR; R_LDR_5.0x4.1mm_P3mm_Vertical
RV1: Pot; Potentiometer_Alpha_RD901F-40-00D_Single_Vertical_mod
SW1: Up; SW_PUSH_8mm_2pin
SW2: Down; SW_PUSH_8mm_2pin
SW3: Left; SW_PUSH_8mm_2pin
SW4: Right; SW_PUSH_8mm_2pin
SW5: A; SW_PUSH_8mm_2pin
SW6: B; SW_PUSH_8mm_2pin
SW7: SW_SPDT; SW_SPDT_Angled
SW8: RESET; SW_PUSH_6mm
U1: Pico; raspberrypi-pico-module
U2: OLED; OLED-SSD1309-SPI

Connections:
+3V3: J2.2, U1.36 (3V3_OUT), U2.2 (VDD)
ADC0: J2.3, U1.31 (GP26_ADC0)
ADC1: RV1.2, U1.32 (GP27_ADC1)
ADC2: R5.1, R6.1, U1.34 (GP28_ADC2)
Buzzer: BZ1.1 (-), U1.14 (GP10)
GND: BZ1.2 (+), J1.1, J2.1, J2.11, R1.1, R2.1, R3.1, R4.1, SW1.2, SW2.2, SW3.2, SW4.2, SW5.2, SW6.2, SW8.2, U1.3 (GND), U1.8 (GND), U1.13 (GND), U1.18 (GND), U1.23 (GND), U1.28 (GND), U1.38 (GND), U2.1 (GND)
GNDA: R6.2, RV1.3, U1.33 (GND_AGND)
GP0: J2.4, U1.1 (GP0)
GP1: J2.6, U1.2 (GP1)
GP2: J2.8, U1.4 (GP2)
GP3: J2.10, U1.5 (GP3)
GP4: J2.9, U1.6 (GP4)
GP5: J2.7, U1.7 (GP5)
GP6: J2.5, U1.9 (GP6)
L_Green: D4.2 (A), U1.27 (GP21)
L_IR: D1.2 (A), U1.29 (GP22)
L_Red: D2.2 (A), U1.12 (GP9)
L_Yellow: D3.2 (A), U1.11 (GP8)
unnamed: D1.1 (K), R4.2
unnamed: D2.1 (K), R1.2
unnamed: D3.1 (K), R2.2
unnamed: D4.1 (K), R3.2
unnamed: D5.2 (A), SW7.3 (C)
unnamed: J1.2, SW7.2 (B)
OLED_CS: U1.22 (GP17), U2.7 (CS)
OLED_DC: U1.21 (GP16), U2.6 (DC)
OLED_RES: U1.26 (GP20), U2.5 (RES)
OLED_SCL: U1.24 (GP18), U2.3 (SCL)
OLED_SDA: U1.25 (GP19), U2.4 (SDA)
RESET: SW8.1, U1.30 (RUN)
SW_A: SW5.1, U1.15 (GP11)
SW_B: SW6.1, U1.10 (GP7)
SW_Down: SW2.1, U1.19 (GP14)
SW_Left: SW3.1, U1.17 (GP13)
SW_Right: SW4.1, U1.16 (GP12)
SW_Up: SW1.1, U1.20 (GP15)
VDDA: R5.2, RV1.1, U1.35 (ADC_VREF)
VSYS: D5.1 (K), J2.12, U1.39 (VSYS)

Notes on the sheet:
Buzzer
Potentiometer
LDR
Reset
LEDs
GPIO
D-Pad
SSD1309 OLED Screen
Raspberry Pi Pico
Battery

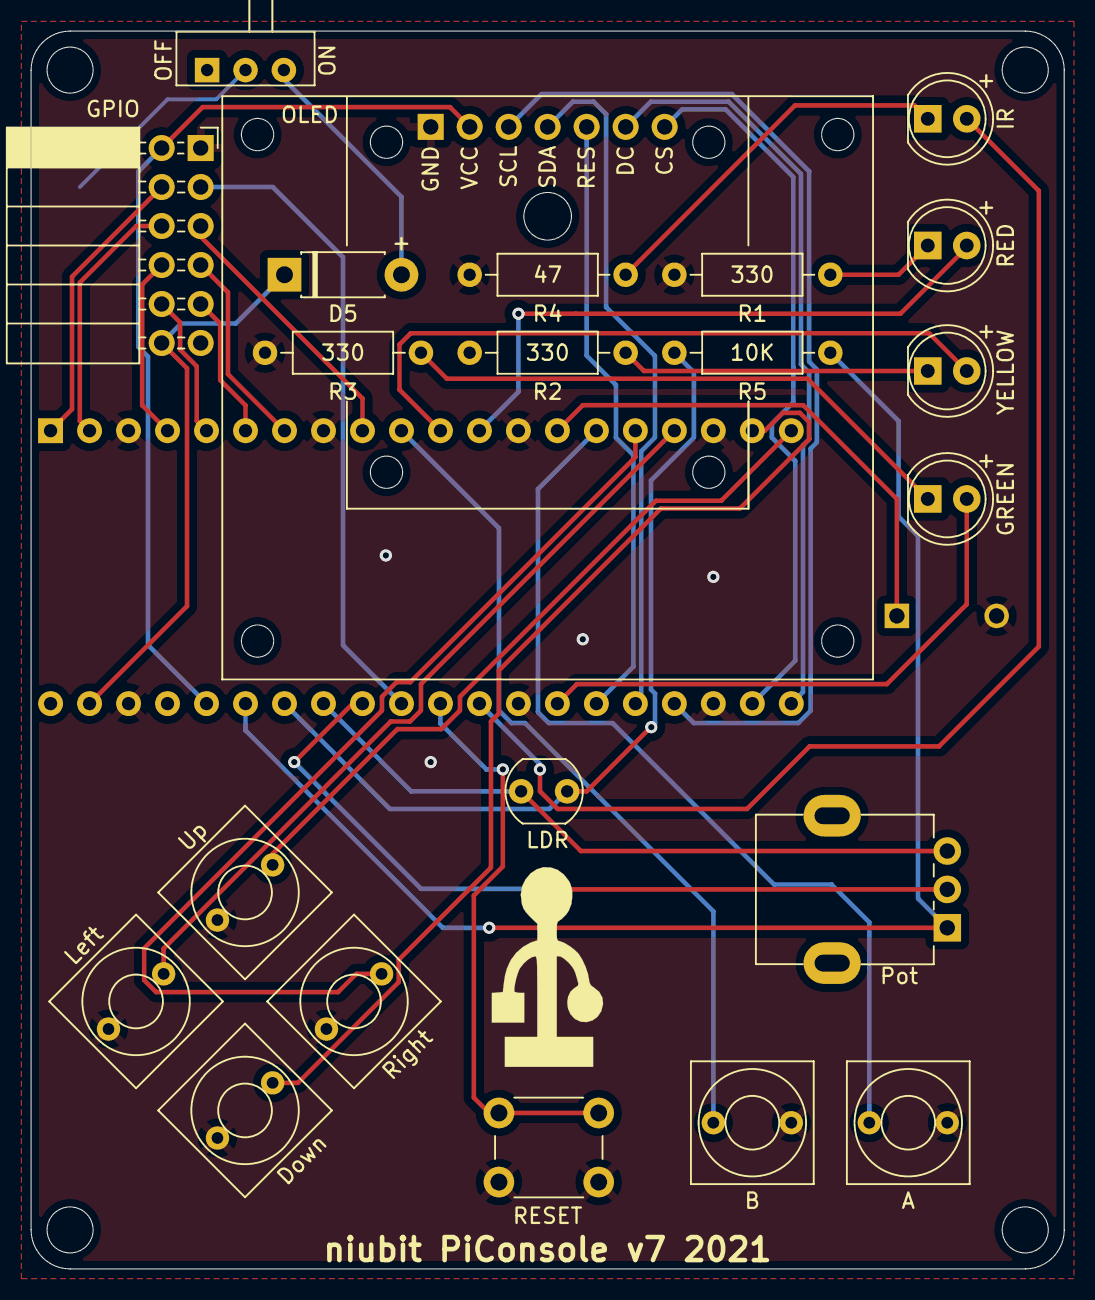
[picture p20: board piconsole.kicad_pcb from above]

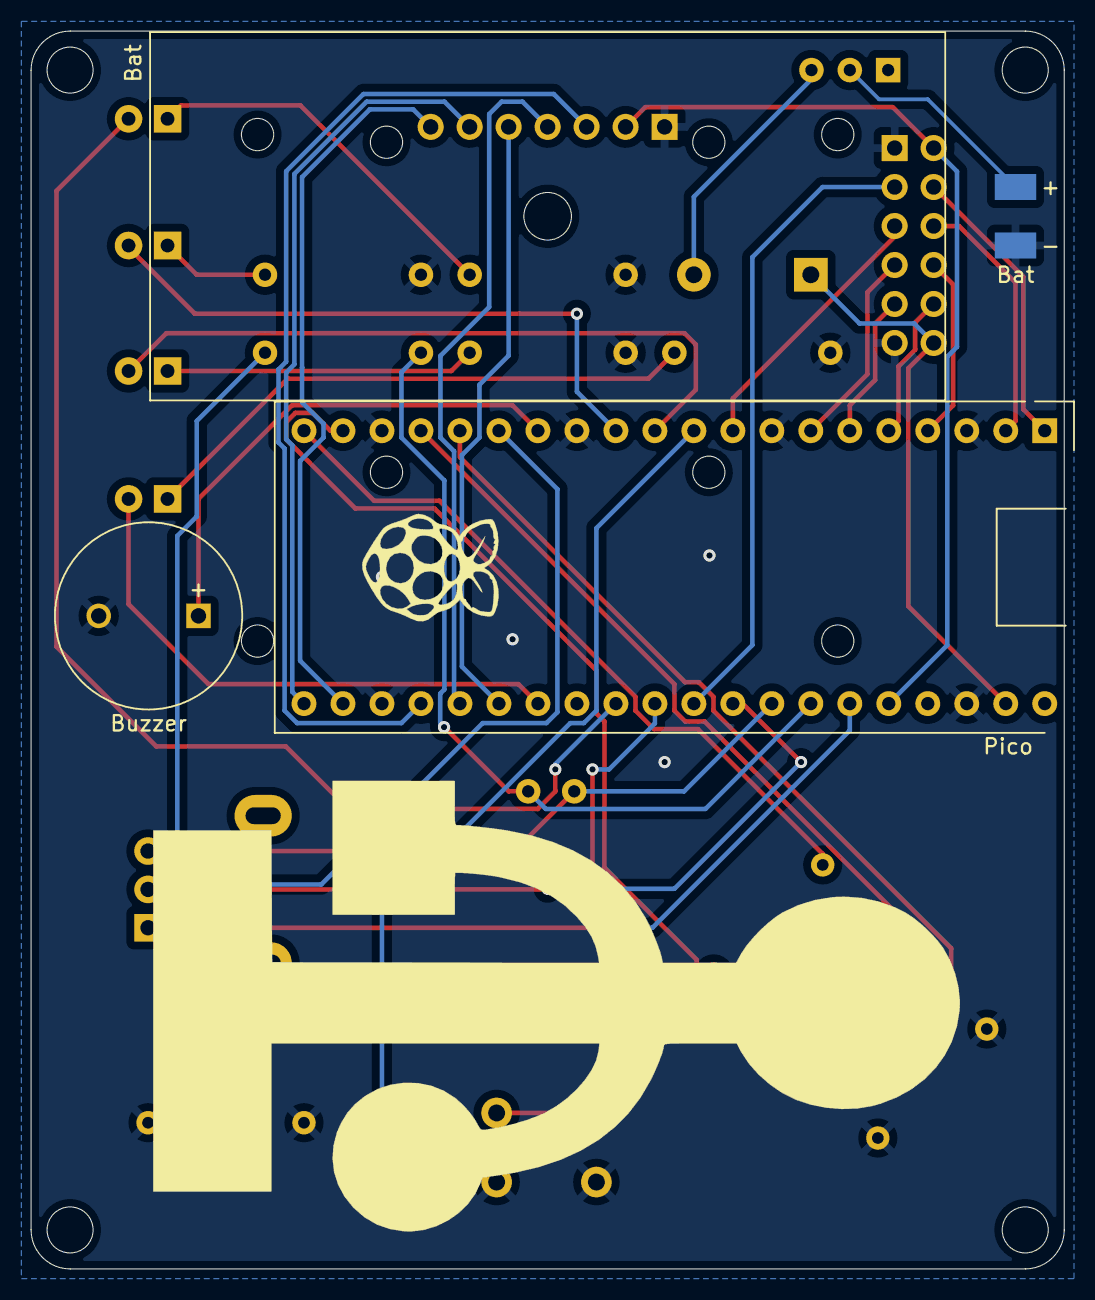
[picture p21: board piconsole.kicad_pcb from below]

Board: 2 copper layers, 67.3 x 80.6 mm, 25 parts (3 on the bottom side), 38 nets.

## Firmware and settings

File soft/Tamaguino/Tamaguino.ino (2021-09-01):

/* Tamaguino
 by Alojz Jakob <http://jakobdesign.com>

 ********** TAMAGUINO ***********
 * Tamagotchi clone for Arduino *
 ********************************
 
*/

#include <SPI.h>
#include <Wire.h>
#include <Adafruit_GFX.h>
#include <Adafruit_SSD1306.h>

#define SCREEN_WIDTH 128 // OLED display width, in pixels
#define SCREEN_HEIGHT 64 // OLED display height, in pixels
#define OLED_DC     16
#define OLED_CS     17
#define OLED_RESET  20
Adafruit_SSD1306 display(SCREEN_WIDTH, SCREEN_HEIGHT,
  &SPI, OLED_DC, OLED_RESET, OLED_CS);

const int button1Pin = 15;  // MENU
const int button2Pin = 14;  // SELECT
const int button3Pin = 12;  // BACK

const int sound = 10; 

int button1State = HIGH;
int button2State = HIGH;
int button3State = HIGH;



// splash 48x26
const unsigned char splash1 [] PROGMEM = {
0x00, 0x00, 0x00, 0x00, 0x00, 0x00, 0x00, 0x39, 0xc0, 0x00, 0x00, 0x00, 0x00, 0x39, 0xc0, 0x00, 
0x00, 0x00, 0x00, 0x39, 0xc0, 0x00, 0x00, 0x00, 0x00, 0x38, 0x00, 0x00, 0x00, 0x00, 0x00, 0x38, 
0x00, 0x00, 0x00, 0x00, 0x07, 0xb9, 0xce, 0x78, 0x0f, 0xc0, 0x0f, 0xf9, 0xcf, 0xfc, 0x1f, 0xe0, 
0x1f, 0xf9, 0xcf, 0xfe, 0x3f, 0xf0, 0x3c, 0x79, 0xcf, 0x1e, 0x38, 0x78, 0x38, 0x39, 0xce, 0x0e, 
0x70, 0x38, 0x38, 0x39, 0xce, 0x0e, 0x70, 0x38, 0x38, 0x39, 0xce, 0x0e, 0x70, 0x38, 0x38, 0x39, 
0xce, 0x0e, 0x70, 0x38, 0x38, 0x39, 0xce, 0x0e, 0x70, 0x38, 0x3c, 0x79, 0xce, 0x0e, 0x78, 0x70, 
0x1f, 0xf9, 0xce, 0x0e, 0x3f, 0xf0, 0x0f, 0xf9, 0xce, 0x0e, 0x1f, 0xe0, 0x00, 0x00, 0x00, 0x00, 
0x00, 0x00, 0x00, 0x02, 0x00, 0x10, 0x00, 0x10, 0x25, 0x37, 0x53, 0x90, 0xe1, 0xb8, 0x29, 0x22, 
0x51, 0xd0, 0x93, 0x90, 0x19, 0x22, 0x52, 0x50, 0x92, 0x10, 0x11, 0x23, 0x73, 0xd0, 0xf1, 0x98, 
0x00, 0x00, 0x00, 0x00, 0x80, 0x00, 0x00, 0x00, 0x00, 0x00, 0x00, 0x00, 
};
//splash dino 80x40
const unsigned char splash2 [] PROGMEM = {
0x00, 0x00, 0x00, 0x00, 0x00, 0x00, 0x00, 0x0f, 0x80, 0x00, 0x00, 0x00, 0x00, 0x00, 0x00, 0x00, 
0x00, 0x1f, 0xff, 0x00, 0x00, 0x00, 0x00, 0x00, 0x00, 0x00, 0x00, 0x39, 0xff, 0xe0, 0x00, 0x00, 
0x00, 0x00, 0x00, 0x00, 0x00, 0x3b, 0xff, 0xf8, 0x00, 0x00, 0x00, 0x00, 0x00, 0x00, 0x00, 0x3f, 
0xe1, 0xfc, 0x00, 0x00, 0x00, 0x00, 0x00, 0x00, 0x00, 0x7f, 0xfe, 0x3e, 0x00, 0x00, 0x00, 0x00, 
0x00, 0x00, 0x00, 0x5e, 0xc1, 0xde, 0x00, 0x00, 0x00, 0x00, 0x00, 0x00, 0x00, 0x7d, 0x80, 0x2f, 
0x00, 0x00, 0x00, 0x00, 0x00, 0x00, 0x00, 0x3a, 0x00, 0x1f, 0x00, 0x00, 0x00, 0x00, 0x00, 0x00, 
0x00, 0x00, 0x00, 0x1f, 0x00, 0x00, 0x00, 0x00, 0x00, 0x00, 0x00, 0x00, 0x00, 0x1f, 0x00, 0x00, 
0x00, 0x00, 0x00, 0x00, 0x00, 0x00, 0x00, 0x1f, 0x00, 0x00, 0x00, 0x00, 0x00, 0x00, 0x00, 0x00, 
0x00, 0x3f, 0x00, 0x00, 0x00, 0x00, 0x00, 0x00, 0x00, 0x00, 0x00, 0xfe, 0x00, 0x00, 0x00, 0x00, 
0x00, 0x00, 0x00, 0x00, 0x01, 0xfa, 0x00, 0x00, 0x00, 0x00, 0x00, 0x00, 0x1f, 0x80, 0x07, 0xf4, 
0x00, 0x00, 0x00, 0x00, 0x00, 0x00, 0xf5, 0xe0, 0x1f, 0xe8, 0x00, 0x00, 0x00, 0x00, 0x00, 0x07, 
0xaa, 0xbc, 0x7f, 0xd0, 0x00, 0x00, 0x00, 0x00, 0x00, 0x3d, 0x55, 0x5f, 0xff, 0xa0, 0x00, 0x00, 
0x00, 0x00, 0x00, 0xea, 0xaa, 0xaf, 0xff, 0x40, 0x00, 0x00, 0x00, 0x00, 0x03, 0xd5, 0x55, 0xff, 
0xfe, 0x80, 0x00, 0x00, 0x00, 0x00, 0x07, 0xab, 0xae, 0xbf, 0xfd, 0x00, 0x00, 0x00, 0x00, 0x00, 
0x1f, 0x5f, 0xdf, 0xff, 0xfa, 0x00, 0x00, 0x00, 0x00, 0x00, 0x3f, 0xee, 0xfb, 0x6f, 0xf4, 0x00, 
0x00, 0x00, 0x00, 0x00, 0xff, 0xff, 0xff, 0xff, 0xe8, 0x00, 0x00, 0x00, 0x00, 0x01, 0xff, 0xf7, 
0xff, 0xff, 0xd0, 0x00, 0x00, 0x00, 0x00, 0x07, 0xff, 0xff, 0xff, 0xff, 0xa0, 0x00, 0x00, 0x00, 
0x00, 0x1f, 0xff, 0xff, 0xff, 0xfd, 0xc0, 0x00, 0x00, 0x00, 0x00, 0xff, 0xdf, 0xff, 0xfe, 0xfe, 
0x80, 0x00, 0x00, 0x00, 0x1f, 0xff, 0xef, 0xef, 0xff, 0x7f, 0x00, 0x00, 0x00, 0x03, 0xff, 0xff, 
0x9f, 0xdf, 0xff, 0xbf, 0x00, 0x00, 0x00, 0xff, 0xff, 0xfc, 0x1f, 0xa1, 0xfc, 0x7f, 0x80, 0x00, 
0x0f, 0xff, 0xff, 0xe0, 0x1f, 0xb0, 0x03, 0xbf, 0x80, 0x00, 0x1f, 0xff, 0x80, 0x00, 0x0f, 0xc0, 
0x00, 0x00, 0x00, 0x00, 0x7e, 0x00, 0x00, 0x00, 0x00, 0x00, 0x00, 0x00, 0x00, 0x00, 0x70, 0x00, 
0x00, 0x00, 0x00, 0x00, 0x00, 0x00, 0x00, 0x00, 0xe0, 0x00, 0x00, 0x00, 0x00, 0x00, 0x00, 0x00, 
0x00, 0x00, 0xc0, 0x00, 0x00, 0x00, 0x00, 0x00, 0x00, 0x00, 0x00, 0x00, 0xc8, 0x00, 0x00, 0x00, 
0x00, 0x00, 0x00, 0x00, 0x00, 0x00, 0x70, 0x00, 0x00, 0x00, 0x00, 0x00, 0x00, 0x00, 0x00, 0x00, 
};


// front grass 32x10
const unsigned char grass_front [] PROGMEM = {
0x00, 0x01, 0x00, 0x00, 0x00, 0x00, 0x80, 0x80, 0x00, 0x08, 0x89, 0xc0, 0x48, 0x5c, 0x50, 0x84, 
0x9c, 0x48, 0x50, 0x22, 0x88, 0x80, 0x44, 0x22, 0x40, 0x84, 0x2e, 0x21, 0x49, 0x24, 0xa4, 0xb1, 
};
//grass 2 (dino walking on) 4x8
const unsigned char grass [] PROGMEM = {
0xff, 0xee, 0xbb, 0x55, 0xaa, 0x11, 
};

//trees
const unsigned char trees [] PROGMEM = {
0x00, 0x00, 0x00, 0x00, 0x00, 0x00, 0x02, 0x00, 0x00, 0x04, 0x00, 0x00, 0x00, 0x00, 0x00, 0x00, 
0x00, 0x00, 0x00, 0x00, 0x00, 0x00, 0x00, 0x00, 0x00, 0x00, 0x00, 0x00, 0x00, 0x00, 0x00, 0x00, 
0x00, 0x10, 0x05, 0x00, 0x00, 0x15, 0x00, 0x00, 0x00, 0x00, 0x00, 0x00, 0x00, 0x00, 0x00, 0x00, 
0x00, 0x40, 0x00, 0x00, 0x00, 0x00, 0x00, 0x00, 0x00, 0x00, 0x00, 0x00, 0x00, 0x28, 0x15, 0x00, 
0x00, 0x55, 0x00, 0x00, 0x00, 0x00, 0x00, 0x00, 0x00, 0x00, 0x00, 0x00, 0x00, 0x00, 0x00, 0x00, 
0x00, 0x00, 0x00, 0x00, 0x00, 0x00, 0x00, 0x00, 0x00, 0x54, 0x55, 0x40, 0x00, 0x55, 0x40, 0x00, 
0x00, 0x00, 0x00, 0x00, 0x00, 0x00, 0x80, 0x00, 0x00, 0x01, 0x00, 0x00, 0x02, 0x00, 0x00, 0x00, 
0x00, 0x00, 0x00, 0x00, 0x00, 0x54, 0x15, 0x04, 0x40, 0x15, 0x00, 0x00, 0x00, 0x00, 0x00, 0x00, 
0x00, 0x02, 0xa0, 0x00, 0x00, 0x01, 0x10, 0x00, 0x08, 0x00, 0x00, 0x00, 0x00, 0x01, 0x00, 0x00, 
0x00, 0x28, 0x84, 0x24, 0x40, 0x04, 0x00, 0x00, 0x00, 0x00, 0x00, 0x04, 0x40, 0x00, 0x82, 0x00, 
0x00, 0x01, 0x10, 0x00, 0x04, 0x40, 0x00, 0x00, 0x00, 0x01, 0x00, 0x02, 0x20, 0x00, 0x00, 0x00, 
0x41, 0x00, 0x10, 0x00, 0x00, 0x00, 0x00, 0x04, 0x40, 0x00, 0x88, 0x82, 0x40, 0x91, 0x04, 0x24, 
0x41, 0x10, 0x00, 0x00, 0x00, 0x01, 0x00, 0x00, 0x00, 0x00, 0x00, 0x00, 0x00, 0x00, 0x00, 0x00, 
0x00, 0x00, 0x00, 0x00, 0x00, 0x10, 0x44, 0x44, 0x11, 0x04, 0x10, 0x11, 0x04, 0x01, 0x00, 0x00, 
0x00, 0x01, 0x00, 0x00, 0x00, 0x00, 0x00, 0x00, 0x00, 0x00, 0x00, 0x00, 0x10, 0x00, 0x00, 0x00, 
0x02, 0x00, 0x00, 0x00, 0x04, 0x00, 0x00, 0x02, 0x10, 0x00, 0x80, 0x00, 0x00, 0x08, 0x00, 0x04, 
0x00, 0x00, 0x00, 0x00, 0x00, 0x40, 0x00, 0x00, 0x04, 0x00, 0x08, 0x00, 0x20, 0x00, 0x01, 0x00, 
0x00, 0x01, 0x00, 0x00, 0x00, 0x00, 0x00, 0x08, 
};

const unsigned char mountains [] PROGMEM = {
0x00, 0x40, 0x00, 0x00, 0x00, 0x00, 0x00, 0x00, 0x00, 0x00, 0x00, 0x00, 0x00, 0x00, 0x00, 0x04, 
0x00, 0xe0, 0x00, 0x00, 0x00, 0x00, 0x00, 0x00, 0x00, 0x00, 0x00, 0x00, 0x00, 0x00, 0x00, 0x0e, 
0x01, 0xf0, 0x00, 0x00, 0x00, 0x00, 0x00, 0x00, 0x00, 0x00, 0x00, 0x00, 0x00, 0x00, 0x00, 0x1f, 
0x03, 0xf8, 0x03, 0x00, 0x00, 0x00, 0x00, 0x00, 0x00, 0x01, 0x00, 0x00, 0x00, 0x00, 0x00, 0x3f, 
0x07, 0x74, 0x07, 0x80, 0x10, 0x00, 0x00, 0x80, 0x00, 0x06, 0x80, 0x00, 0x00, 0x00, 0x00, 0xd5, 
0x0e, 0xc2, 0x0d, 0xc0, 0x28, 0x01, 0x01, 0xc1, 0x00, 0x1f, 0x40, 0x00, 0x00, 0x00, 0x01, 0x28, 
0x1d, 0x13, 0x1b, 0x60, 0x54, 0x03, 0x83, 0xa3, 0x80, 0x36, 0x20, 0x00, 0x00, 0x00, 0x06, 0xd0, 
0x3a, 0x41, 0xb4, 0x30, 0xe2, 0xcc, 0xf7, 0x57, 0xc0, 0xd8, 0x10, 0x00, 0x00, 0x00, 0x19, 0x20, 
0x68, 0x84, 0x49, 0x19, 0xa1, 0x36, 0x5d, 0x2a, 0xa1, 0xa0, 0x10, 0x00, 0x00, 0x00, 0xe6, 0x40, 
0xd2, 0x10, 0xa4, 0x0c, 0x80, 0x8c, 0x1a, 0x15, 0x57, 0x40, 0x88, 0x00, 0x00, 0x1f, 0x38, 0x80, 
0x49, 0x08, 0x00, 0x06, 0x02, 0xc0, 0x24, 0x18, 0x0b, 0x80, 0x05, 0x0b, 0x8c, 0xe0, 0x23, 0x00, 
0xa0, 0x20, 0x00, 0x11, 0x00, 0x00, 0x48, 0x84, 0x84, 0x02, 0x20, 0x5d, 0xf3, 0x00, 0xcd, 0xc0, 
0x50, 0x00, 0x04, 0x04, 0x01, 0x44, 0x00, 0x00, 0x08, 0x00, 0x00, 0x30, 0x04, 0x07, 0x10, 0x20, 
0x00, 0x00, 0x00, 0x00, 0x04, 0x00, 0x00, 0x00, 0x00, 0x08, 0x00, 0x00, 0x40, 0x40, 0x00, 0x10, 
0x40, 0x02, 0x00, 0x00, 0x00, 0x00, 0x00, 0x81, 0x00, 0x00, 0x00, 0x01, 0x11, 0x01, 0x00, 0x00, 
0x00, 0x00, 0x00, 0x00, 0x40, 0x00, 0x00, 0x00, 0x00, 0x00, 0x80, 0x80, 0x00, 0x00, 0x20, 0x02, 
};


const unsigned char cloud2 [] PROGMEM = {
0x04, 0x70, 0x18, 0x00, 0x6e, 0xfb, 0x7c, 0xee, 0xff, 0xff, 0xfd, 0xff, 0x6f, 0xfb, 0x38, 0xee, 
0x07, 0x70, 0x52, 0x00, 
};



// walking sprites
// walk right
const unsigned char dinoWalk0 [] PROGMEM = {
0x00, 0x00, 0x00, 0x00, 0x00, 0x00, 0x00, 0x00, 0x00, 0x00, 0x00, 0x00, 0x00, 0x00, 0x00, 0x00, 
0x00, 0x00, 0x00, 0x00, 0x00, 0x00, 0x00, 0x00, 0x00, 0x00, 0x00, 0x00, 0x00, 0x00, 0x00, 0x00, 
0x00, 0x00, 0x00, 0x00, 0x00, 0x00, 0x00, 0x00, 0x00, 0x00, 0x00, 0x00, 0x00, 0x00, 0x00, 0x00, 
0x00, 0x00, 0x00, 0x00, 0x00, 0x00, 0x00, 0x00, 0x00, 0x00, 0x00, 0x00, 0x00, 0x00, 0x00, 0x00, 
0x00, 0x00, 0x00, 0x00, 0x00, 0x00, 0x00, 0x00, 0x00, 0x00, 0x00, 0x00, 0x00, 0x00, 0x00, 0x00, 
0x00, 0x00, 0x00, 0x00, 0x00, 0x00, 0x00, 0x00, 0x00, 0x00, 0x00, 0x00, 0x07, 0xc0, 0x60, 0x00, 
0x00, 0x00, 0x1f, 0xf1, 0xf0, 0x00, 0x00, 0x00, 0x3f, 0xff, 0xb8, 0x00, 0x00, 0x00, 0x7b, 0xff, 
0xfc, 0x00, 0x00, 0x00, 0xff, 0xff, 0xd8, 0x00, 0x00, 0x03, 0xff, 0x7f, 0xe0, 0x00, 0x00, 0x0f, 
0xf7, 0xde, 0x00, 0x00, 0x00, 0x7f, 0xf8, 0x3c, 0x00, 0x00, 0x00, 0x00, 0xbc, 0x7a, 0x00, 0x00,
};
const unsigned char dinoWalk1 [] PROGMEM = {
0x00, 0x00, 0x00, 0x00, 0x00, 0x00, 0x00, 0x00, 0x00, 0x00, 0x00, 0x00, 0x00, 0x00, 0x00, 0x00, 
0x00, 0x00, 0x00, 0x00, 0x00, 0x00, 0x00, 0x00, 0x00, 0x00, 0x00, 0x00, 0x00, 0x00, 0x00, 0x00, 
0x00, 0x00, 0x00, 0x00, 0x00, 0x00, 0x00, 0x00, 0x00, 0x00, 0x00, 0x00, 0x00, 0x00, 0x00, 0x00, 
0x00, 0x00, 0x00, 0x00, 0x00, 0x00, 0x00, 0x00, 0x00, 0x00, 0x00, 0x00, 0x00, 0x00, 0x00, 0x00, 
0x00, 0x00, 0x00, 0x00, 0x00, 0x00, 0x00, 0x00, 0x00, 0x00, 0x00, 0x00, 0x00, 0x00, 0x00, 0x00, 
0x00, 0x00, 0x00, 0x00, 0x00, 0x00, 0x00, 0x00, 0x00, 0x00, 0x00, 0x00, 0x07, 0xc0, 0x60, 0x00, 
0x00, 0x00, 0x1f, 0xf1, 0xf0, 0x00, 0x00, 0x00, 0x37, 0xff, 0xb8, 0x00, 0x00, 0x00, 0x7f, 0xff, 
0xfc, 0x00, 0x00, 0x00, 0xff, 0x7f, 0xd8, 0x00, 0x00, 0x03, 0xff, 0xff, 0xe0, 0x00, 0x00, 0x0f, 
0xbf, 0xda, 0x00, 0x00, 0x00, 0x7f, 0xf8, 0x3c, 0x00, 0x00, 0x00, 0x00, 0x30, 0x18, 0x00, 0x00, 
};
const unsigned char dinoWalk2 [] PROGMEM = {
0x00, 0x00, 0x00, 0x00, 0x00, 0x00, 0x00, 0x00, 0x00, 0x00, 0x00, 0x00, 0x00, 0x00, 0x00, 0x00, 
0x00, 0x00, 0x00, 0x00, 0x00, 0x00, 0x00, 0x00, 0x00, 0x00, 0x00, 0x00, 0x00, 0x00, 0x00, 0x00, 
0x00, 0x00, 0x00, 0x00, 0x00, 0x00, 0x00, 0x00, 0x00, 0x00, 0x00, 0x00, 0x00, 0x00, 0x00, 0x00, 
0x00, 0x00, 0x00, 0x00, 0x00, 0x00, 0x00, 0x00, 0x00, 0x00, 0x00, 0x00, 0x00, 0x00, 0x00, 0x00, 
0x00, 0x00, 0x00, 0x00, 0x00, 0x00, 0x00, 0x00, 0x00, 0x00, 0x00, 0x00, 0x00, 0x00, 0x00, 0x00, 
0x00, 0x00, 0x00, 0x00, 0x00, 0x00, 0x00, 0x00, 0x00, 0x00, 0x00, 0x00, 0x07, 0xc0, 0x60, 0x00, 
0x00, 0x00, 0x1b, 0xf1, 0xf0, 0x00, 0x00, 0x00, 0x3f, 0xff, 0xb8, 0x00, 0x00, 0x00, 0x7f, 0x7f, 
0xfc, 0x00, 0x00, 0x00, 0xff, 0xff, 0xd8, 0x00, 0x00, 0x03, 0xff, 0xff, 0xe0, 0x00, 0x00, 0x0f, 
0xbf, 0xfa, 0x00, 0x00, 0x00, 0x7f, 0x78, 0x3c, 0x00, 0x00, 0x00, 0x00, 0xf4, 0x5e, 0x00, 0x00,
};
// walk left
const unsigned char dinoWalk3 [] PROGMEM = {
0x00, 0x00, 0x00, 0x00, 0x00, 0x00, 0x00, 0x00, 0x00, 0x00, 0x00, 0x00, 0x00, 0x00, 0x00, 0x00, 
0x00, 0x00, 0x00, 0x00, 0x00, 0x00, 0x00, 0x00, 0x00, 0x00, 0x00, 0x00, 0x00, 0x00, 0x00, 0x00, 
0x00, 0x00, 0x00, 0x00, 0x00, 0x00, 0x00, 0x00, 0x00, 0x00, 0x00, 0x00, 0x00, 0x00, 0x00, 0x00, 
0x00, 0x00, 0x00, 0x00, 0x00, 0x00, 0x00, 0x00, 0x00, 0x00, 0x00, 0x00, 0x00, 0x00, 0x00, 0x00, 
0x00, 0x00, 0x00, 0x00, 0x00, 0x00, 0x00, 0x00, 0x00, 0x00, 0x00, 0x00, 0x00, 0x00, 0x00, 0x00, 
0x00, 0x00, 0x00, 0x00, 0x00, 0x00, 0x00, 0x00, 0x00, 0x00, 0x00, 0x06, 0x03, 0xe0, 0x00, 0x00, 
0x00, 0x0f, 0x8f, 0xf8, 0x00, 0x00, 0x00, 0x1d, 0xff, 0xfc, 0x00, 0x00, 0x00, 0x3f, 0xff, 0xde, 
0x00, 0x00, 0x00, 0x1b, 0xff, 0xff, 0x00, 0x00, 0x00, 0x07, 0xfe, 0xff, 0xc0, 0x00, 0x00, 0x00, 
0x7b, 0xef, 0xf0, 0x00, 0x00, 0x00, 0x3c, 0x1f, 0xfe, 0x00, 0x00, 0x00, 0x5e, 0x3d, 0x00, 0x00,  
};
const unsigned char dinoWalk4 [] PROGMEM = {
0x00, 0x00, 0x00, 0x00, 0x00, 0x00, 0x00, 0x00, 0x00, 0x00, 0x00, 0x00, 0x00, 0x00, 0x00, 0x00, 
0x00, 0x00, 0x00, 0x00, 0x00, 0x00, 0x00, 0x00, 0x00, 0x00, 0x00, 0x00, 0x00, 0x00, 0x00, 0x00, 
0x00, 0x00, 0x00, 0x00, 0x00, 0x00, 0x00, 0x00, 0x00, 0x00, 0x00, 0x00, 0x00, 0x00, 0x00, 0x00, 
0x00, 0x00, 0x00, 0x00, 0x00, 0x00, 0x00, 0x00, 0x00, 0x00, 0x00, 0x00, 0x00, 0x00, 0x00, 0x00, 
0x00, 0x00, 0x00, 0x00, 0x00, 0x00, 0x00, 0x00, 0x00, 0x00, 0x00, 0x00, 0x00, 0x00, 0x00, 0x00, 
0x00, 0x00, 0x00, 0x00, 0x00, 0x00, 0x00, 0x00, 0x00, 0x00, 0x00, 0x06, 0x03, 0xe0, 0x00, 0x00, 
0x00, 0x0f, 0x8f, 0xf8, 0x00, 0x00, 0x00, 0x1d, 0xff, 0xec, 0x00, 0x00, 0x00, 0x3f, 0xff, 0xfe, 
0x00, 0x00, 0x00, 0x1b, 0xfe, 0xff, 0x00, 0x00, 0x00, 0x07, 0xff, 0xff, 0xc0, 0x00, 0x00, 0x00, 
0x5b, 0xfd, 0xf0, 0x00, 0x00, 0x00, 0x3c, 0x1f, 0xfe, 0x00, 0x00, 0x00, 0x18, 0x0c, 0x00, 0x00, 
};
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
void loop() {
  delay(40);
  button1State = digitalRead(button1Pin);
  button2State = digitalRead(button2Pin);
  button3State = digitalRead(button3Pin);
  //char* str = "";
  
  if(!dead){
    /* -------- MODIFY PET STATS -------- */
    // TODO: different gradients regarding to age
    if(sleeping){
      hunger-=0.00005;
      poopometer+=0.00005;
      if(happiness-0.0001>0){
        happiness-=0.0001;
      }
      health-=0.00005+countPoops()*0.0001;
      if(discipline-0.0001>0){
        discipline-=0.0001;
      }
    }else{
      hunger-=0.00025;
      poopometer+=0.00025;
      if(happiness-0.0002>0){
        happiness-=0.0002;
      }
      health-=0.0001+countPoops()*0.0001;
      if(discipline-0.0002>0){
        discipline-=0.0002;
      }
      //discipline-=0.02;
    }
    age+=0.0000025;

    //diarrhea :) for testing
    //poopometer+=0.005;

    //health-=1;
    //health-=countPoops()*0.0001;
    //health-=countPoops()*0.05;

    if(poopometer>=10){
      int poopometer2=countPoops();
      poops[poopometer2]=random(20,display.width()+32);
      if(soundEnabled){
        tone(sound,200,50);
        noTone(sound);
      }
      poopometer=0;
    }

    if((hunger>19.99975 && hunger<20.00025) || (happiness>19.9998 && happiness<20.0002) || (health>19.9999 && health<20.0001) && soundEnabled){
      if(soundEnabled){
        tone(sound,200,50);
        noTone(sound);
      }
    }
  
    
    if(hunger<=20 || countPoops()>0 || happiness<=20 || health<=20){
      notification=true;  
    }
    if(hunger>20 && countPoops()==0 && happiness>20 && health>20){
      notification=false;  
      digitalWrite(13,LOW);
    }

    if(hunger<=0 || health<=0 || happiness<=0){
      dead=true;
      if(soundEnabled){
        tone(sound,500,500);
        delay(550);
        tone(sound,400,500);
        delay(550);
        tone(sound,300,600);
        noTone(sound);
      }
    }

  
    display.clearDisplay();
    display.setCursor(0,0);
  
  
    /* ------- BUTTON PRESS ACTIONS ------- */
    
    /* ------- BUTTON 1 - MENU ------- */
    if(button1State==LOW){
      delay(40);
      // JUMP IN GAME
      if(game){

        if(!jumping && !paused){
          if(soundEnabled){
            tone(sound,200,50);
            noTone(sound);
          }
          jumping=true;
        }
        
      }else{
        // MENU

        if(soundEnabled){
          tone(sound,300,80);
          noTone(sound);
        }
      
        if(!menuOpened){
          menuOpened=true;
        }else{
          if(menuDepth){

            if((const char*)pgm_read_word(&(mainMenu[menu][subMenu+1]))==NULL){
              subMenu=1;
            }else{
              ++subMenu;
            }
            setting=100*(menu+1)+subMenu;
          }else{
            if(menu==MENUSIZE-1){
              menu=0;
            }else{
              ++menu;
            }
            
            if((const char*)pgm_read_word(&(mainMenu[menu][1]))!=NULL){
              subMenu=1;
              
              justOpened=true;
            }
            setting=100*(menu+1)+subMenu;
          }
        }

        delay(60);
        
      }
      
    }
    /* ------- BUTTON 2 - SELECT ------- */
    if(button2State==LOW){
      delay(40);
      if(game){
        if(!gameOver){
          paused=!paused;
          if(soundEnabled){
            tone(sound,600,80);
            noTone(sound);
          }
          delay(60);
        }
        
      }else{

        if(soundEnabled){
          tone(sound,600,80);
          noTone(sound);
        }
        
        if(menuOpened){

          if(subMenu!=1 && (const char*)pgm_read_word(&(mainMenu[menu][1][0]))!=NULL){
            action=100*(menu+1)+subMenu; 
          }
          if(subMenu==1 && (const char*)pgm_read_word(&(mainMenu[menu][1][0]))==NULL){
            action=100*(menu+1)+subMenu;
          }
          if(subMenu==1 && (const char*)pgm_read_word(&(mainMenu[menu][1][0]))!=NULL && menuDepth){
            action=100*(menu+1)+subMenu; 
          }
          if((const char*)pgm_read_word(&(mainMenu[menu][1][0]))!=NULL){
            setting=100*(menu+1)+subMenu;
            menuDepth=true;
          }
          
        }else{
          action=NULL;
          
          menuOpened=true;
          menuDepth=true;
          subMenu=1;
          menu=6;
          action=701;
          setting=701;
        }
        justOpened=false;

        delay(60);
        
      }
      
    }
    /* ------- BUTTON 3 - BACK ------- */
    if(button3State==LOW){
      delay(40);
      if(soundEnabled){
        tone(sound,1000,80);
        noTone(sound);
      }
      
      if(game || gameOver){
        walkPos=0;
        walkXPos=0;
        walkAnimReverse=false;
        walkRight=true;
        walkDirOffset=0;
        treesXPos=-20;
        grassXPos=0;
        obstacle1show=false;
        obstacle2show=false;
        jumping=false;
        jumpPos=0;
        jumpUp=true;
        game=false;
        score=0;
        newHiScore=false;
        gameOver=false;
        level=0;
        paused=false;
      }else{
        if(!menuDepth){
          menuOpened=false;
          menu=0;
          setting=0;
        }else{
          menuDepth=false;
          setting=100*(menu+1)+1;
        }
        action=NULL;
        subMenu=1;
      }

     
      delay(60);
    }
  
  
  
    /* ------- SCENERY AND WALKING ------- */
  
    //draw sun
    sunXPos+=0.1;
    if(sunXPos>display.width()+2*sunRadius){
      sunXPos=-2*sunRadius;
      sunOrMoon=!sunOrMoon;
    }
    if(sleeping) {sunOrMoon=true;}
    
    if(sleeping){
      sunOrMoon=true;
    }
    
    if(!sunOrMoon){
      display.fillCircle(sunXPos,2*sunRadius,sunRadius,WHITE);
    }else{
      display.fillCircle(sunXPos,2*sunRadius,sunRadius,WHITE);
      display.fillCircle(sunXPos-moonShadow,2*sunRadius,sunRadius,BLACK);
      //if(walkPos == 5){
      if(int(round(cloud1XPos)) % 5 == 0){
        for(int i=0;i<6;i++){
          stars[i][0]=random(0,display.width());
          stars[i][1]=random(0,10);
        }
      }else{
        for(int i=0;i<6;i++){
          
          display.drawPixel(stars[i][0],stars[i][1],WHITE);
        }
      }
    }
  
    //cloud 1
    cloud1XPos-=0.3;
    if(cloud1XPos<-cloud1Width){
      cloud1XPos=display.width()+cloud1Width;
    }
    display.drawBitmap(cloud1XPos, 5, cloud2 , cloud1Width, 5, WHITE);

    
    //mountains
    display.drawBitmap(0, 7, mountains , 128, 16, WHITE);
  
    //walk and move ground perspective

    if(game){

      
      /* ------ GAME -----*/
      level=round(score/10);

      if(jumping && !gameOver && !paused){
        if(jumpUp){
          jumpPos=jumpPos+1+level;
          if(jumpPos>=12){
            jumpUp=false;
          }
        }else{
          //jumpPos--;
          jumpPos=jumpPos-1-level;
          if(jumpPos<=0){
            jumpUp=true;
            jumping=false;
            if(soundEnabled){
              tone(sound,100,50);
              noTone(sound);
            }
            score+=1;
          }
        }
      }


      if(!gameOver && !paused){
        if(walkAnimReverse){
          walkPos-=1;
          if(walkPos==-1){walkPos=0; walkAnimReverse=false;}
        }else{
          walkPos+=1;
          if(walkPos==3){walkPos=2; walkAnimReverse=true;}
        }

        
        
        walkXPos+=2;
        grassXPos+=4;
        treesXPos=treesXPos+1+level;
        obstacle1XPos=obstacle1XPos+2+level;
        obstacle2XPos=obstacle2XPos+2+level;

        
        if(!jumping && 
            (
              (obstacle1show && display.width()-obstacle1XPos>=20 && display.width()-obstacle1XPos<=46)
              || 
              (obstacle2show && display.width()-obstacle2XPos>=20 && display.width()-obstacle2XPos<=46)
            )
          ){
          gameOver=true;
          jumping=true;
          jumpPos=-2;
          if(soundEnabled){
            tone(sound,500,40);
            delay(50);
            tone(sound,350,40);
            delay(50);
            tone(sound,200,60);
            noTone(sound);
          }

          if(score>hiScore){
            hiScore=score;
            newHiScore=true;
          }
          if(happiness+15<100){
            happiness+=15;
          }else{
            happiness=100;
          }
          health-=1;
          if(weight-score*0.0025>5){
            weight-=score*0.0025;
          }
          
          
        }
      }
      
      if(walkXPos==display.width()){
        walkXPos=0;
      }
      if(grassXPos==display.width()){grassXPos=0;}
      if(treesXPos==display.width()){treesXPos=-128;}
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

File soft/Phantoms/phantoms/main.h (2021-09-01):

/*
 * Phantom Slayer
 *
 * @version     1.0.2
 * @author      smittytone
 * @copyright   2021, Tony Smith
 * @licence     MIT
 *
 */
#ifndef _PHANTOMS_MAIN_HEADER_
#define _PHANTOMS_MAIN_HEADER_


// Standard, Pico includes
#include <stdbool.h>
#include <stdlib.h>
#include <stdio.h>
#include <string.h>
#include <time.h>
#include "pico/stdlib.h"
#include "pico/binary_info.h"
#include "hardware/gpio.h"
#include "hardware/spi.h"
#include "hardware/adc.h"

// Game includes
#include "gfx.h"
#include "map.h"
#include "phantoms.h"
#include "ssd1306.h"
#include "tinymt32.h"
#include "utils.h"


/*
 * STRUCTURE DEFINITIONS
 */
typedef struct {
    uint8_t  x;
    uint8_t  y;
    uint8_t  width;
    uint8_t  height;
    uint8_t  spot;
} Rect;

typedef struct {
    uint8_t  x;
    uint8_t  y;
    uint8_t  hp;
    uint8_t  hp_max;
    uint8_t  direction;
    uint8_t  back_steps;
} Phantom;

typedef struct {
    bool     in_play;
    bool     show_reticule;
    bool     can_fire;
    bool     is_firing;
    bool     can_teleport;
    bool     is_joystick_centred;
    bool     show_compass;

    uint8_t  phantoms;
    uint8_t  audio_range;
    uint8_t  tele_x;
    uint8_t  tele_y;
    uint8_t  start_x;
    uint8_t  start_y;
    uint8_t  level_kills;
    uint8_t  map;

    uint16_t level;
    uint16_t level_score;
    uint16_t high_score;

    uint32_t zap_time;
    uint32_t debounce_count_press;
    uint32_t debounce_count_release;
    uint32_t phantom_speed;
} Game;


/*
 * PROTOTYPES
 */
void    setup();
void    play_intro();
void    create_world();
void    init_game();

void    game_loop();
bool    check_joystick(uint16_t x, uint16_t y) ;
uint8_t get_direction(uint16_t x, uint16_t y);

void    update_world(uint32_t now);
void    check_senses();

void    do_teleport();
void    fire_laser();

void    death();
void    show_scores();


/*
 *  CONSTANTS
 */
#define SPI_PORT                                        spi0

#define ON                                              true
#define OFF                                             false

#define PIN_DC                                          16
#define PIN_CS                                          17
#define PIN_SCL                                         18  //SCK
#define PIN_SDA                                         19  //MOSI
#define SSD1306_RST_PIN                                 20
#define PIN_SPEAKER                                     10
#define PIN_TELE_BUTTON                                 7
#define PIN_FIRE_BUTTON                                 11
#define PIN_LED                                         25
#define PIN_RIGHT                                       12
#define PIN_LEFT                                        13
#define PIN_DOWN                                        14
#define PIN_UP                                          15

// Player movement directions
#define DIRECTION_NORTH                                 0
#define DIRECTION_EAST                                  1
#define DIRECTION_SOUTH                                 2
#define DIRECTION_WEST                                  3

#define MOVE_FORWARD                                    0
#define TURN_RIGHT                                      1
#define MOVE_BACKWARD                                   2
#define TURN_LEFT                                       3

// Joystick
#define UPPER_LIMIT                                     2448
#define LOWER_LIMIT                                     1648
#define JOY_MAX                                         4096

// Timer limits
#define DEBOUNCE_TIME_US                                5000
#define ANIM_TIME_US                                    22000
#define PHANTOM_MOVE_TIME_US                            1000000
#define LASER_RECHARGE_US                               2000000
#define MAP_POST_KILL_SHOW_MS                           3000

// Map square types
#define MAP_TILE_WALL                                   0xEE
#define MAP_TILE_CLEAR                                  0xFF
#define MAP_TILE_TELEPORTER                             0xAA
#define MAX_VIEW_RANGE                                  5

#define MAX_PHANTOMS                                    3
#define ERROR_CONDITION                                 99
#define PHANTOM_NORTH                                   1
#define PHANTOM_EAST                                    2
#define PHANTOM_SOUTH                                   4
#define PHANTOM_WEST                                    8


/*
 *  GLOBALS
 */
uint8_t     oled_height;
uint8_t     oled_width;
bool        oled_inverted;

// Graphics buffer
uint8_t     oled_buffer[1024];
uint8_t     temp_buffer[1024];
uint8_t     side_buffer[1024];
uint8_t     spi_tx_buffer[1025];
uint16_t    oled_buffer_size;
uint16_t    spi_tx_buffer_size;

uint8_t     *draw_buffer;

// Player
uint8_t     player_x;
uint8_t     player_y;
uint8_t     player_direction;

// Graphics structures
Rect        rects[7];

// Game data
Phantom     phantoms[3];
Game        game;
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

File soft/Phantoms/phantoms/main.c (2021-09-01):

/*
 * Phantom Slayer
 *
 * @version     1.0.2
 * @author      smittytone
 * @copyright   2021, Tony Smith
 * @licence     MIT
 *
 */
#include "main.h"


/*
 *  Initialisation Functions
 */
void setup() {
    // Set up the game hardware

    // Set up SPI
    spi_init(SPI_PORT, 500000);
    gpio_set_function(PIN_SCL, GPIO_FUNC_SPI);
    gpio_set_function(PIN_SDA, GPIO_FUNC_SPI);

    // Configure Chip Select
    gpio_init(PIN_CS); // Initialise CS Pin
    gpio_set_dir(PIN_CS, GPIO_OUT); // Set CS as output
    gpio_put(PIN_CS, 1); // Set CS High to indicate no currect SPI communication

    // Configure DC
    gpio_init(PIN_DC); // Initialise DC Pin
    gpio_set_dir(PIN_DC, GPIO_OUT); // Set DC as output

    // Set up the OLED
    ssd1306_init(128, 64);

    // Set up the speaker
    gpio_init(PIN_SPEAKER);
    gpio_set_dir(PIN_SPEAKER, GPIO_OUT);
    gpio_put(PIN_SPEAKER, false);

    // Set up the Fire button
    gpio_init(PIN_FIRE_BUTTON);
    gpio_set_dir(PIN_FIRE_BUTTON, GPIO_IN);
    gpio_pull_up(PIN_FIRE_BUTTON);

    // Set up the Teleport button
    gpio_init(PIN_TELE_BUTTON);
    gpio_set_dir(PIN_TELE_BUTTON, GPIO_IN);
    gpio_pull_up(PIN_TELE_BUTTON);

    // Set up the direction buttons
    gpio_init(PIN_RIGHT);
    gpio_set_dir(PIN_RIGHT, GPIO_IN);
    gpio_pull_up(PIN_RIGHT);
    gpio_init(PIN_LEFT);
    gpio_set_dir(PIN_LEFT, GPIO_IN);
    gpio_pull_up(PIN_LEFT);
    gpio_init(PIN_UP);
    gpio_set_dir(PIN_UP, GPIO_IN);
    gpio_pull_up(PIN_UP);
    gpio_init(PIN_DOWN);
    gpio_set_dir(PIN_DOWN, GPIO_IN);
    gpio_pull_up(PIN_DOWN);

    // Use one of the Pico's other analog inputs
    // to seed the random number generator
    adc_init();
    adc_gpio_init(28);
    adc_select_input(2);
    srand(adc_read());

    // Randomise using TinyMT
    // https://github.com/MersenneTwister-Lab/TinyMT
    tinymt32_init(&tinymt_store, adc_read());

    // Set up the LED to flash with the speaker
    gpio_init(PIN_LED);
    gpio_set_dir(PIN_LED, GPIO_OUT);
    gpio_put(PIN_LED, false);

    // Make the graphic frame rects
    // NOTE These are pixel values:
    //      left, top, width, height, Phantom lateral offset
    uint8_t coords[] = { 0,  0, 128, 64, 44,     // Outer LED frame
                        11,  5, 106, 54, 31,
                        24, 10,  80, 44, 21,
                        36, 15,  56, 34, 14,
                        47, 20,  34, 24,  8,
                        55, 25,  18, 14,  4,
                        61, 27,   6, 10, 63};    // 'End wall' for distant views

    // Read the array values into Rect structures
    uint8_t count = 0;
    for (uint8_t i = 0 ; i < sizeof(coords) ; i += 5) {
        Rect a_rect;
        a_rect.x = coords[i];
        a_rect.y = coords[i + 1];
        a_rect.width = coords[i + 2];
        a_rect.height = coords[i + 3];
        a_rect.spot = coords[i + 4];
        rects[count++] = a_rect;
    }

    // Set the address of the buffer we'll draw to
    draw_buffer = &oled_buffer[0];
}


void init_game() {
    // Reset the main game control structure
    game.in_play = false;
    game.show_reticule = false;
    game.is_firing = false;
    game.can_teleport = false;
    game.is_joystick_centred = true;
    game.show_compass = false;
    game.level_score = 0;
    game.audio_range = 4;
    game.phantoms = 1;
    game.level = 1;
    game.zap_time = 0;
    game.debounce_count_press = 0;
    game.debounce_count_release = 0;
    game.tele_x = 0;
    game.tele_y = 0;
    game.start_x = 0;
    game.start_y = 0;
    game.phantom_speed = PHANTOM_MOVE_TIME_US << 1;

    // If these demo/test modes are both set,
    // chase mode takes priority
    chase_mode = false;
    map_mode = false;

    // FROM 1.0.2
    // Store the current map number so it's not
    // used in subsequent games
    game.map = ERROR_CONDITION;
}


void init_phantoms() {
    // Reset the array stored phantoms structures
    for (uint8_t i = 0 ; i < 3 ; ++i) {
        Phantom* p = &phantoms[i];
        p->x = ERROR_CONDITION;
        p->y = ERROR_CONDITION;
        p->hp = 1;
        p->hp_max = 1;
        p->direction = 0;
        p->back_steps = false;
    }
}
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

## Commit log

2021-08-20 Commit inicial.
    [ALPHA-RD901F-40.step, OLED TFT 0.96 inch 64x128 monochrome.STEP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]
2021-08-28 Avances carcasa.
    [case.FCStd, cruceta.stl, piconsole.kicad_pcb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]
2021-08-30 Tecla reset.
    [case.FCStd, tecla_reset.stl]
2021-08-30 Tecla reset más alta.
    [case.FCStd, tecla_reset.stl]
2021-08-31 Se agrandan ligeramente los agujeros de la PCB.
    [piconsole-B_Cu.gbl, piconsole-B_Mask.gbs, piconsole-B_Paste.gbp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]
2021-09-01 Modificación altura labio tecla reset.
    [case.FCStd, tecla_reset.stl]
2021-09-01 Ajuste hueco pantalla.
    [case.FCStd, superior.stl]
2021-09-01 Tapa inferior.
    [case.FCStd, inferior.stl]
2021-09-01 Recuperación de backup de juegos perdidos al unificar repositorios.
2021-09-02 Marcas en carcasa superior para pin 1 de GPIO y ON/OFF.
    [case.FCStd, superior.stl]
2021-09-08 Leyenda para conector GPIO.
2021-10-01 Modelo 3D (step) de Raspberry Pi Pico.
    [Pico-R3.step]
2021-10-01 Colección de juegos de Thumby portada.
    [thumby.cfg]
2021-10-06 Datasheet de Adafruit para pantalla OLED SSD1306.
2021-10-06 Se añade librería SSD1306 a proyecto de 'CoderDojo_Twin_Cities'.
2021-10-06 Más detalle de directorio 'CoderDojo_Twin_Cities'.
2021-10-06 Mejoras colección cheungbx.
    Mejora en librería gameESP. Se sustituyen retornos de carro Windows por Linux.
2021-10-25 Directorio para juegos basados en Thumby.
2021-11-18 Carriles de los controles más altos y mejor sentados.
    [case.FCStd, superior.stl]
2021-11-19 Se agranda el espacio para el labio de los controles A y B.
    [case.FCStd, superior.stl]
2021-11-19 Más espacio para la cruceta.
    [case.FCStd, superior.stl]
2021-12-03 v7. Enrutado más directo a LED IR.
    [piconsole-B_Cu.gbl, piconsole-B_Mask.gbs, piconsole-B_Paste.gbp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]
2021-12-17 Logo de niubit en carcasa inferior.
    [case.FCStd]
2021-12-17 Texto niubit en carcasa superior.
    [case.FCStd]
2021-12-20 STLs con logos niubit.
    [inferior.stl, inferior_liso.stl, superior.stl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]
2021-12-20 Se traspasa el directorio 'soft' a un repo público.
    [thumby.cfg]
2021-12-22 Logo niubit en carcasa inferior menos profundo.
    [case.FCStd, inferior.stl]
2021-12-22 Enlace a repositorio de soft.
2021-12-23 Se recolocan referencias de algunos componentes.
    Bat y Pico para que no las oculten los propios componentes.
    [piconsole-B_Cu.gbl, piconsole-B_Mask.gbs, piconsole-B_Paste.gbp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]
2022-01-04 Adaptado a KiCad 6.
    [piconsole.kicad_pcb, piconsole.kicad_sch]
2022-01-19 Nueva v7 (aún no se había fabricado)
    [piconsole-B_Cu.gbl, piconsole-B_Mask.gbs, piconsole-B_Paste.gbp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]
2022-02-02 Se separa una via de un par
    Estaba demasiado próxima.
    [piconsole.kicad_pcb]
2022-03-14 Se adaptan rutas de modelos 3D componentes
    [Raspberry_Pi_Pico.step, piconsole.kicad_pcb]
2022-04-12 Color in top and bottom case
    [case.FCStd]
2022-04-13 Soft directory
    [thumby.cfg]
